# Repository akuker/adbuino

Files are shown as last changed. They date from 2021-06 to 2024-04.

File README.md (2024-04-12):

# Background

"Adbuino" has a long history of different people tinkering with it. Just to provide some clarity...

- ORIGINAL PS/2 version - In the beginning - bbraun created the adbuino project and generously open sourced it. The links aren't working anymore, but the original SVN repo was [bbraun's](http://synack.net/svn/adbduino/)
- Difegue PS/2 version - 2020 - Difegue's version of the [adbuino](https://github.com/Difegue/Chaotic-Realm), modified [bbraun's](http://synack.net/svn/adbduino/) version, with some extra code added to alleviate issues with his own PS/2 keyboard.
- akuker USB version - 2022 - akuker converted Difegue's version to use a USB controller and created a PCB design using KiCad.
- [QuokkADB](QuokkADB.md) - 2023 - [Rabbit Hole computing](https://github.com/rabbitholecomputing) created a new PCB based on the RP2040 (instead of Atmel chip). [Morio](https://github.com/morio), ported the code to the dual core RP2040, removed the dependency on the expensive MAX3421E USB controller and updated it to a PlatformIO project. Morio graciously merged their code changes back into [akuker/adbuino](http://github.com/akuker/adbuino)
- [HIDHopper_ADB](https://github.com/TechByAndroda/HIDHopper_ADB) - 2023 - [TechByAndroda](https://github.com/TechByAndroda) forked the repo and made a new PCB that uses a Raspberry Pi Pico (instead of a chip-down RP2040)

Its GPL code. It belongs to the community. Do fun GPL stuff with it. 

# akuker USB Adbuino
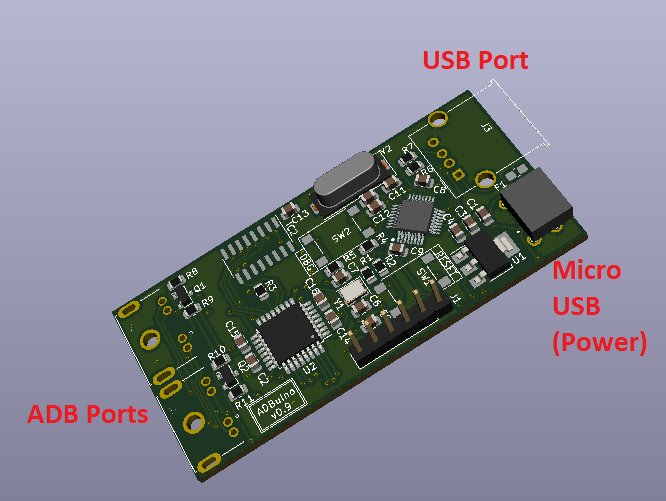
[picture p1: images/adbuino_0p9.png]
ADBuino picture

This is a fork of Difegue's version of the [adbuino](https://github.com/Difegue/Chaotic-Realm), which was a modified version of [bbraun's](http://synack.net/svn/adbduino/) PS/2 to ADB arduino sketch, with some extra code added to alleviate issues with his own PS/2 keyboard.  For Difegue's original write-up, please read more info [here.](https://tvc-16.science/adbuino-ps2.html).

# QuokkADB
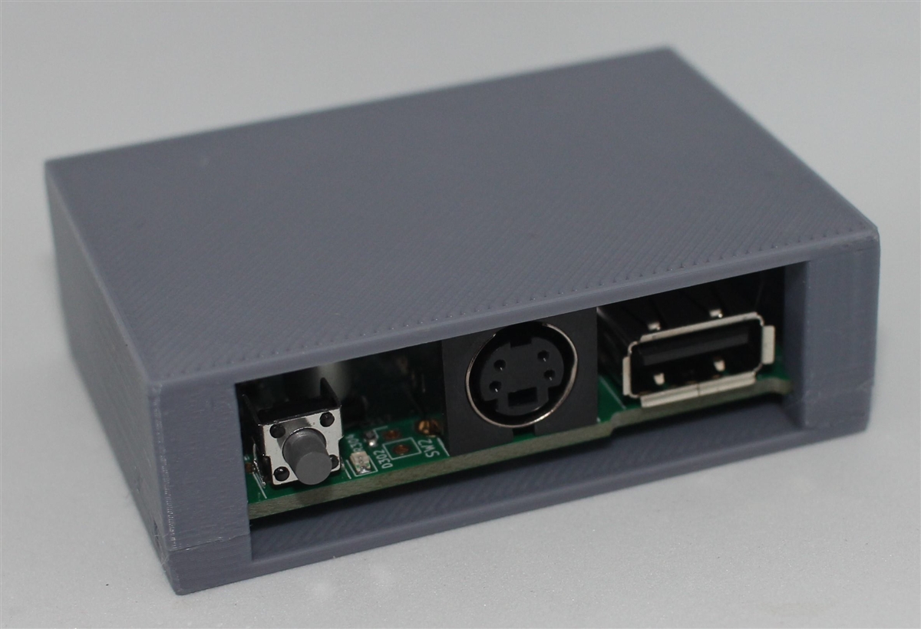
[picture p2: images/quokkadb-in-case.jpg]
QuokkADB picture

QuokkADB is a modified version of [adbuino](https://github.com/akuker/adbuino). It is targeted to the Rabbit Hole Computing's QuokkADB device. QuokkADB is a Raspberry Pi RP2040 based device that takes in USB inputs from a keyboard and/or mouse and outputs Apple's ADB (Apple Desktop Bus).  Further information can be found in the [QuokkADB.md](QuokkADB.md) file. 

# HIDHopper_ADB
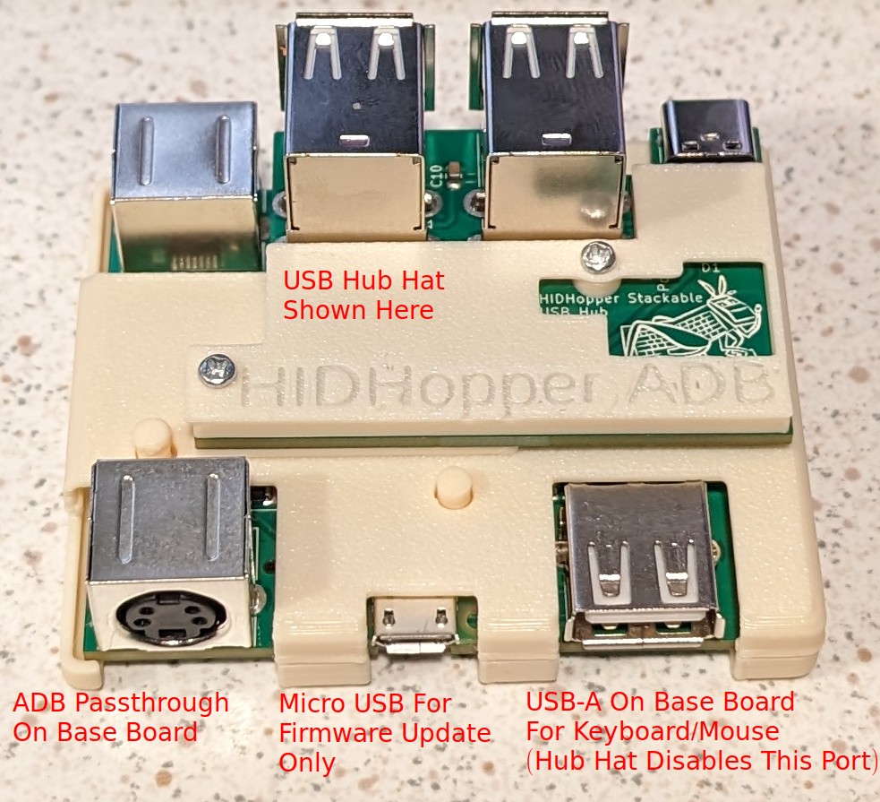
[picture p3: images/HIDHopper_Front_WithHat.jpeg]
HIDHopper picture

HIDHopper_ADB is a modified (forked) version of adbuino and QuokkADB. It is a Raspberry Pi Pico based hardware device which converts USB keyboard and mouse inputs to the Apple Desktop Bus (ADB) standard.

# Hack-y Alternative
The USB ADBuino is essentially a "value-engineered" version of a bunch of off-the-shelf components. 

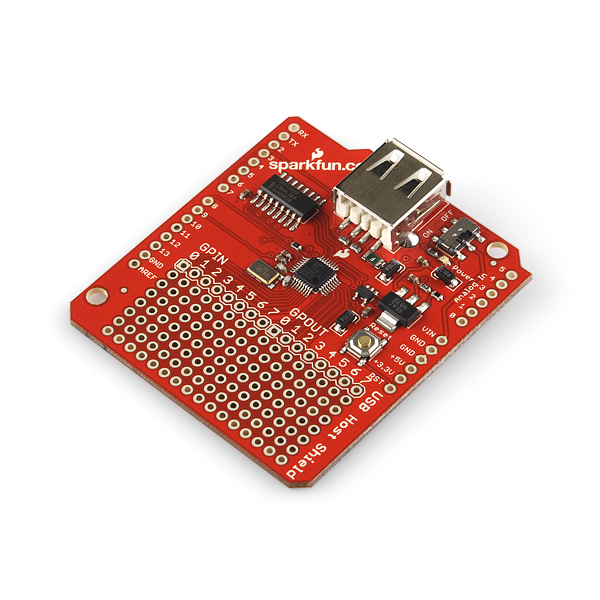
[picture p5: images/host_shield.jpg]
  
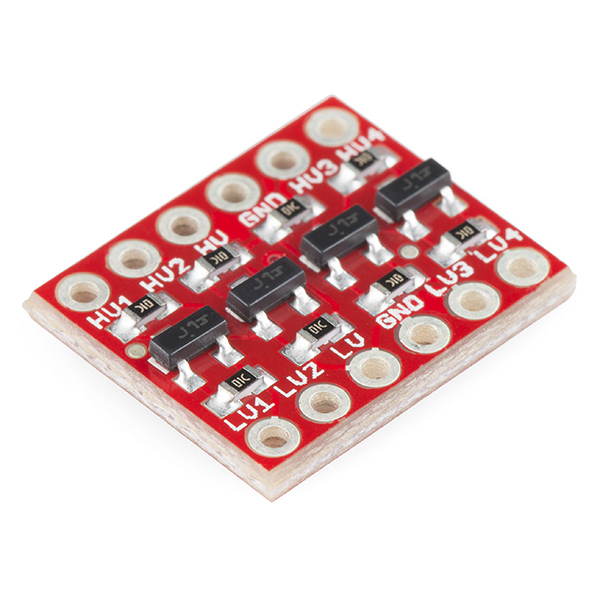
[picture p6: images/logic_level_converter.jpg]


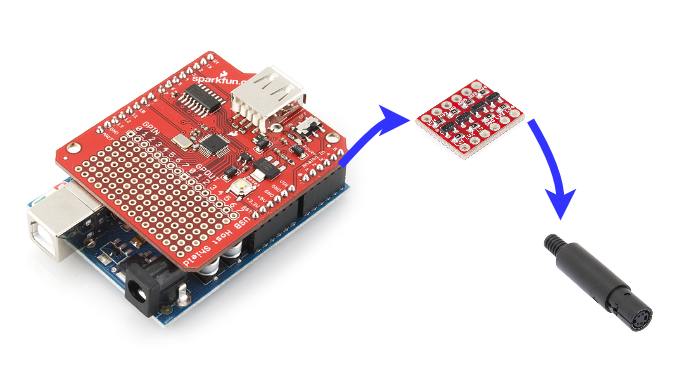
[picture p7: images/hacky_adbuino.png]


# How to build and flash an adbuino

Note: This software is intended to be compiled in an Ubuntu Linux environment.

Any dependencies that are configured in the PlatformIO project (such as TinyUSB) will automatically be downloaded. Make sure you are connected to the Internet the first time you build this software.

- Install [Visual Studio Code](https://code.visualstudio.com/)
- Install [Platform IO](https://platformio.org/install)
- Open Visual studio Code and open the directory ./src/adbuino
- Select the PlatformIO icon on the left
- Execute the `Build` project task
- Execute the `Upload` project task to flash your device

# What's this repo for?

The intent of this repository is to add "USB Host" support to the original ADB design. This will allow a USB keyboard and/or mouse to be used to drive an ADB host, as well as PS/2. 

The [BMOW "Wombat"](https://www.bigmessowires.com/usb-wombat/) is a closed-source alternative to adbuino. The [BMOW "Wombat"](https://www.bigmessowires.com/usb-wombat/) is an AWESOME project, but doesn't allow external contributors. 

# References
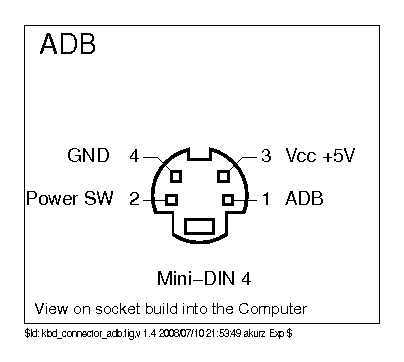
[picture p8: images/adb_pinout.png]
ADB Pinout


## Protocol/Software Documentation
- [Apple ADB Manager Documenation](https://developer.apple.com/library/archive/documentation/mac/pdf/Devices/ADB_Manager.pdf)
- [ADB Overview](https://www.lopaciuk.eu/2021/03/26/apple-adb-protocol.html)
- [Microchip Application Note AN591](http://www.t-es-t.hu/download/microchip/an591b.pdf)
- [TMK Documentation](https://github.com/tmk/tmk_keyboard/wiki/Apple-Desktop-Bus)

## Other libraries
- [TinyUSB Library](https://github.com/raspberrypi/tinyusb)
- [MiSTER adb hardware emulation](https://github.com/mist-devel/plus_too/blob/master/adb.v)

## Development resources
- [Running OpenOCD without root](https://forgge.github.io/theCore/guides/running-openocd-without-sudo.html)

## Hardware Links
- [ADB Connector - mouser](https://www.mouser.com/ProductDetail/TE-Connectivity/5749181-1?qs=XlZqES4cpWbRcAMR%2FcJqkQ%3D%3D)

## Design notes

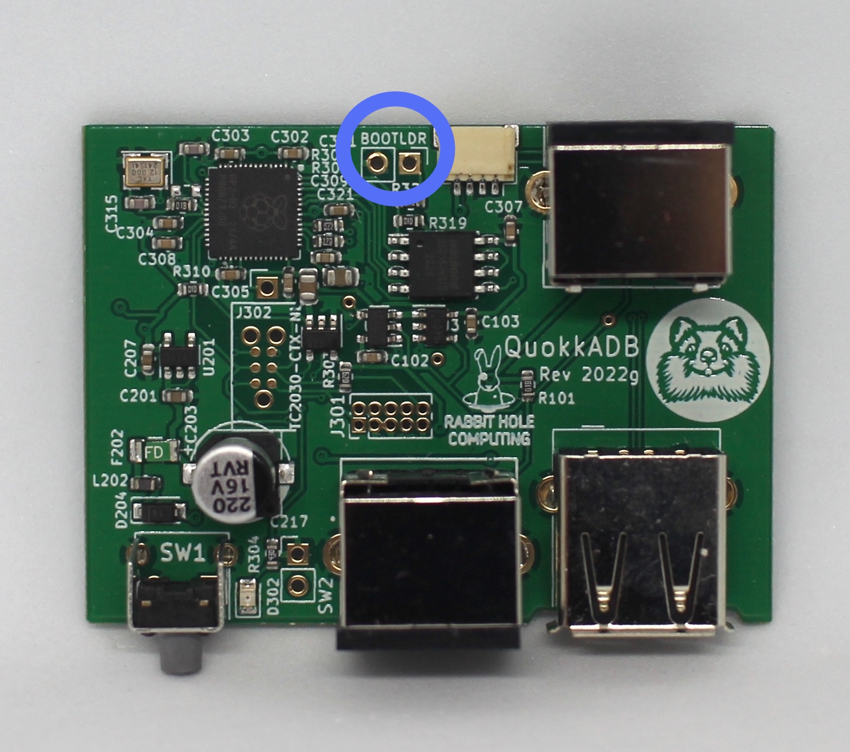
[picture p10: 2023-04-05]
images/quokkadb-bootloader.jpg

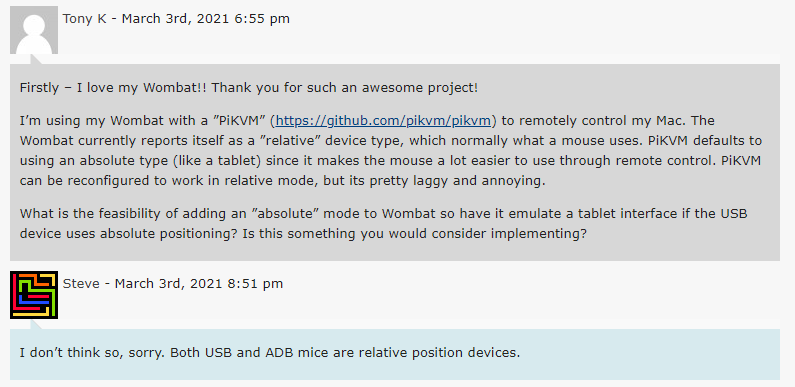
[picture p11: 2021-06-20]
images/wombat_discussion.png

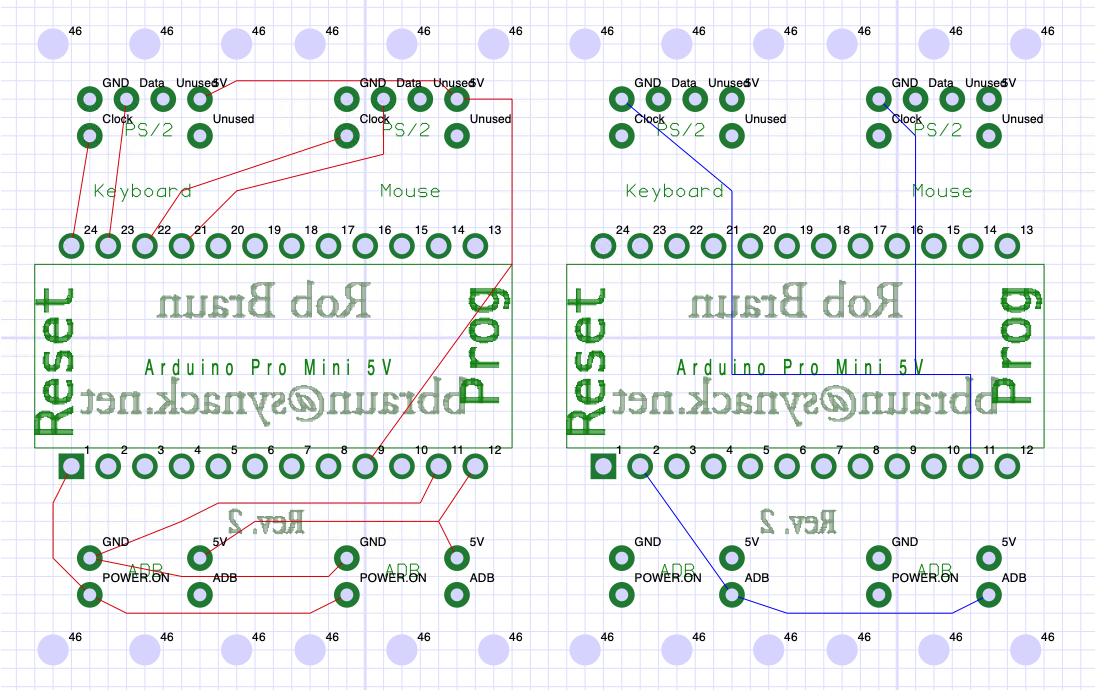
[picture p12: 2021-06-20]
hw/osmond.png

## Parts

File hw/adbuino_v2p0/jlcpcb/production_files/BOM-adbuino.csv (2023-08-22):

Comment | Designator | Footprint | LCSC
LED_Small | D1,D2,D3 | LED_0805_2012Metric | C2297
10k | R1,R12,R2,R3,R4,R5,R6 | R_0402_1005Metric | C25744
U254-051N-4BH806 | J2 | U254051N4BH806 | C319170
Polyfuse | F1,F2 | Fuse_0805_2012Metric | C66452
BSS138 | Q1,Q2 | SOT-23 | C78284
D_Schottky | D4,D5 | D_SOD-123 | C8598
Mini-DIN-4 | J5 | CUI_MD2-40ST-SMT
Pico | U2 | Customized_RPi_Pico_SMD_TH
TestPoint_Small | TP3 | TestPoint_Pad_D1.0mm
TestPoint_Small | TP2 | TestPoint_Pad_D1.0mm
TestPoint_Small | TP1 | TestPoint_Pad_D1.0mm
Mini-DIN-4 | J4 | CUI_MD2-40ST-SMT
SolderJumper_2_Open | JP5 | SolderJumper-2_P1.3mm_Open_RoundedPad1.0x1.5mm

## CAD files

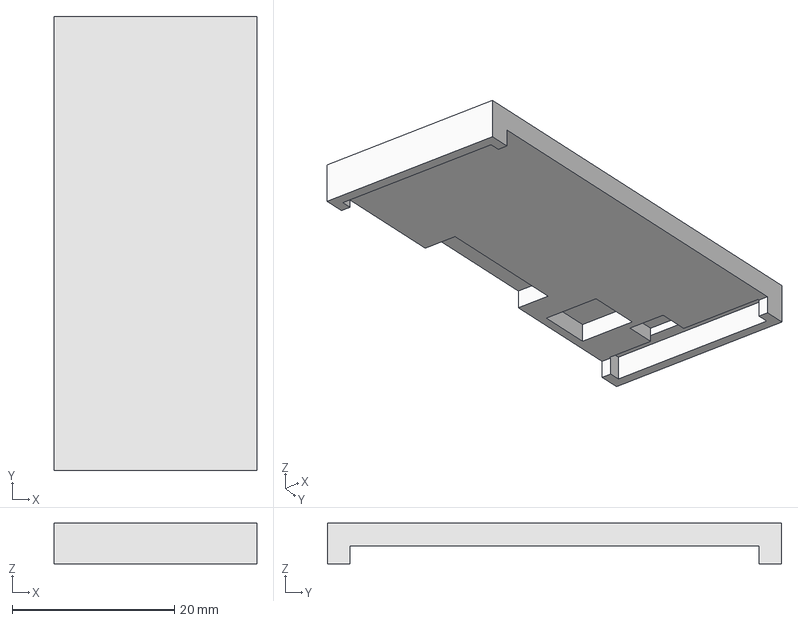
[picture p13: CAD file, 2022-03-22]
case/adbuino_case2.FCStd
25.0 x 56.0 x 5.00 mm

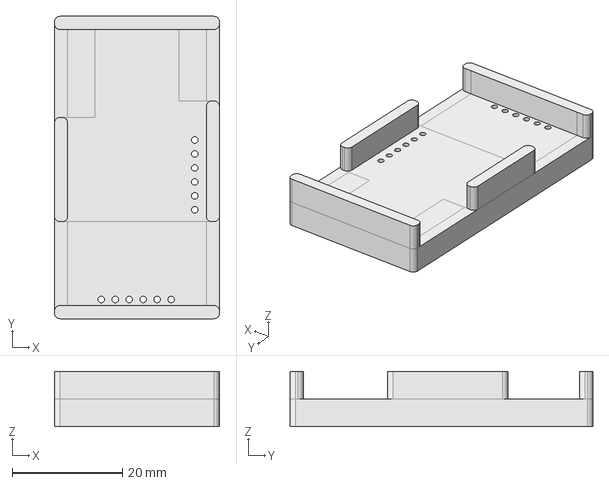
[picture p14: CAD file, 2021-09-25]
hw/adbuino_pogo_holder/adbuino_pogo_holder.FCStd
30.0 x 55.0 x 10.0 mm

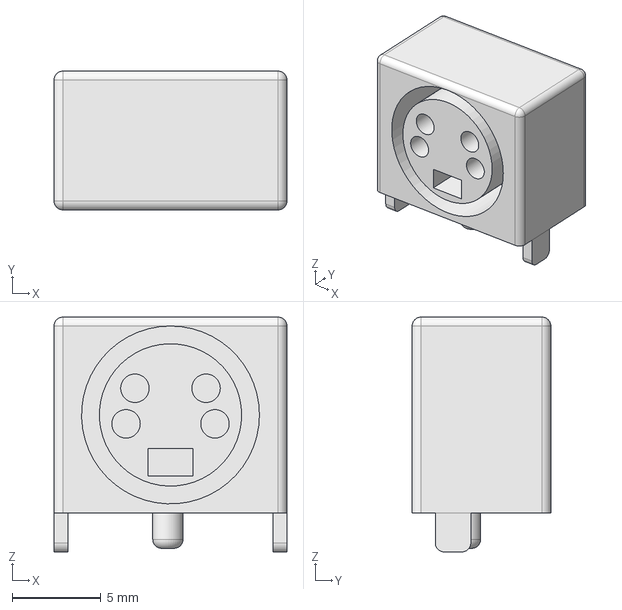
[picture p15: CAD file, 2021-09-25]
hw/adbuino_v2p0/MD2-40ST-SMT.FCStd
13.1 x 7.80 x 13.2 mm

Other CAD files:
hw/adbuino_pogo_holder/adbuino_pogo_holder.stl

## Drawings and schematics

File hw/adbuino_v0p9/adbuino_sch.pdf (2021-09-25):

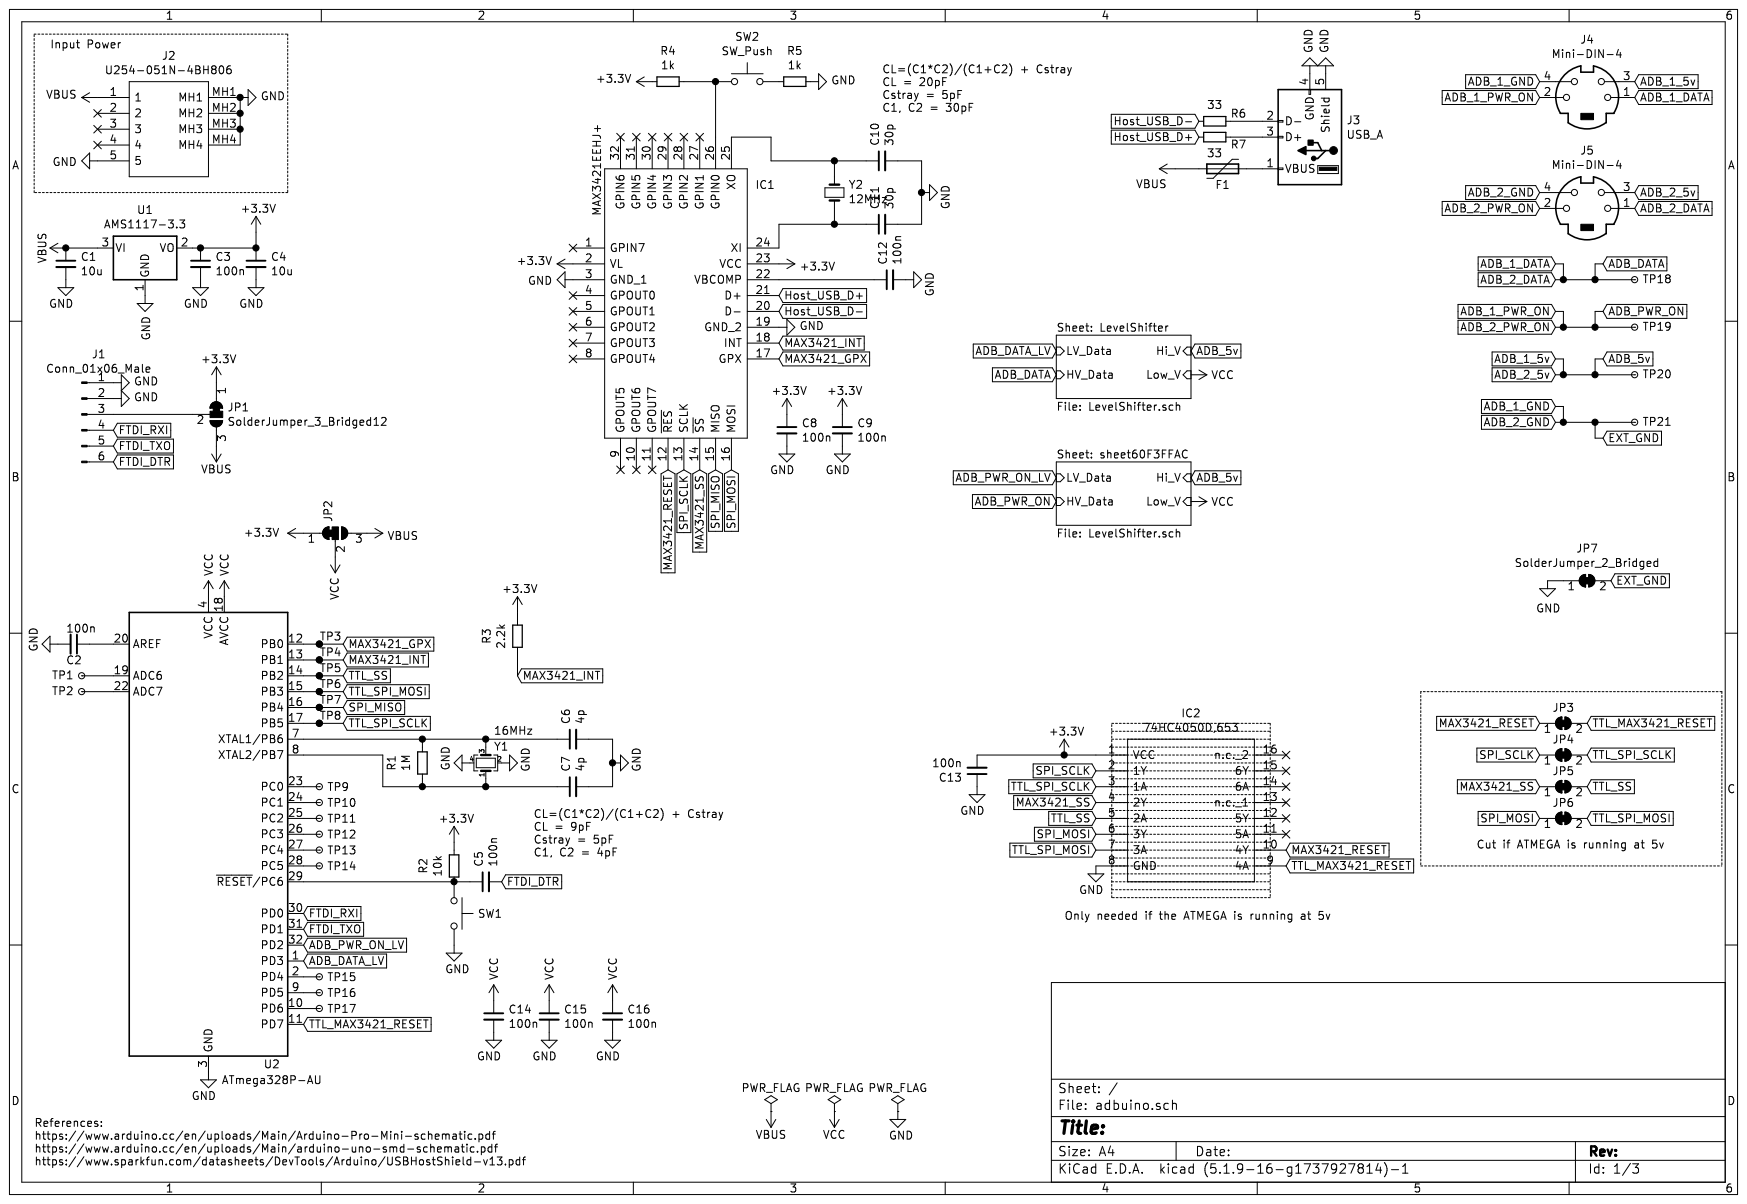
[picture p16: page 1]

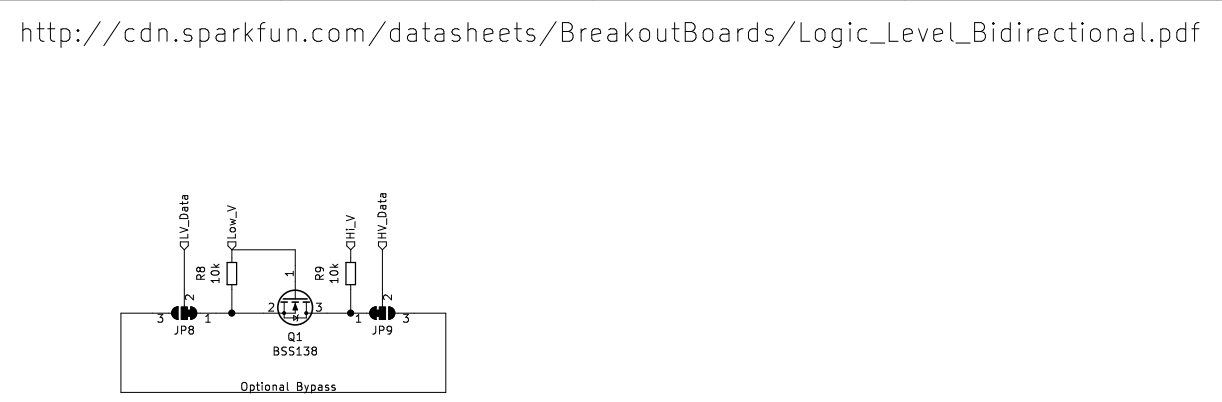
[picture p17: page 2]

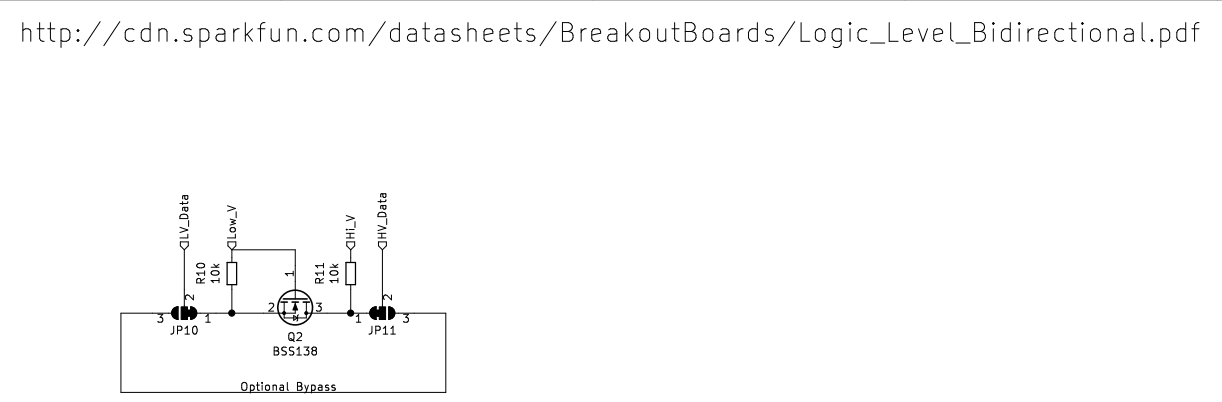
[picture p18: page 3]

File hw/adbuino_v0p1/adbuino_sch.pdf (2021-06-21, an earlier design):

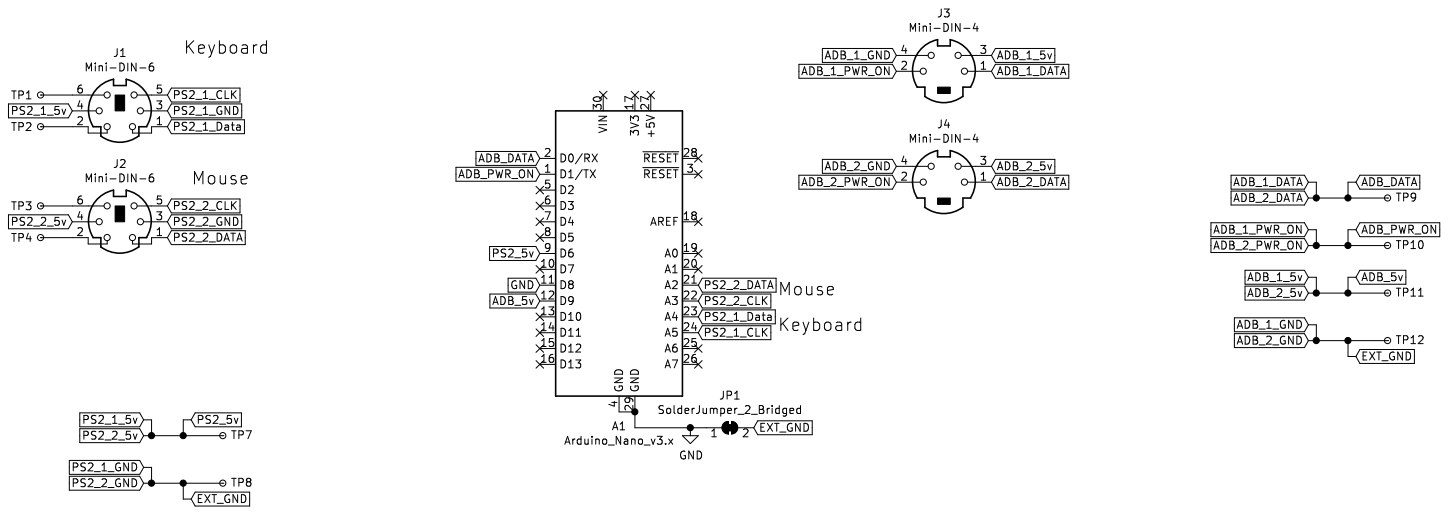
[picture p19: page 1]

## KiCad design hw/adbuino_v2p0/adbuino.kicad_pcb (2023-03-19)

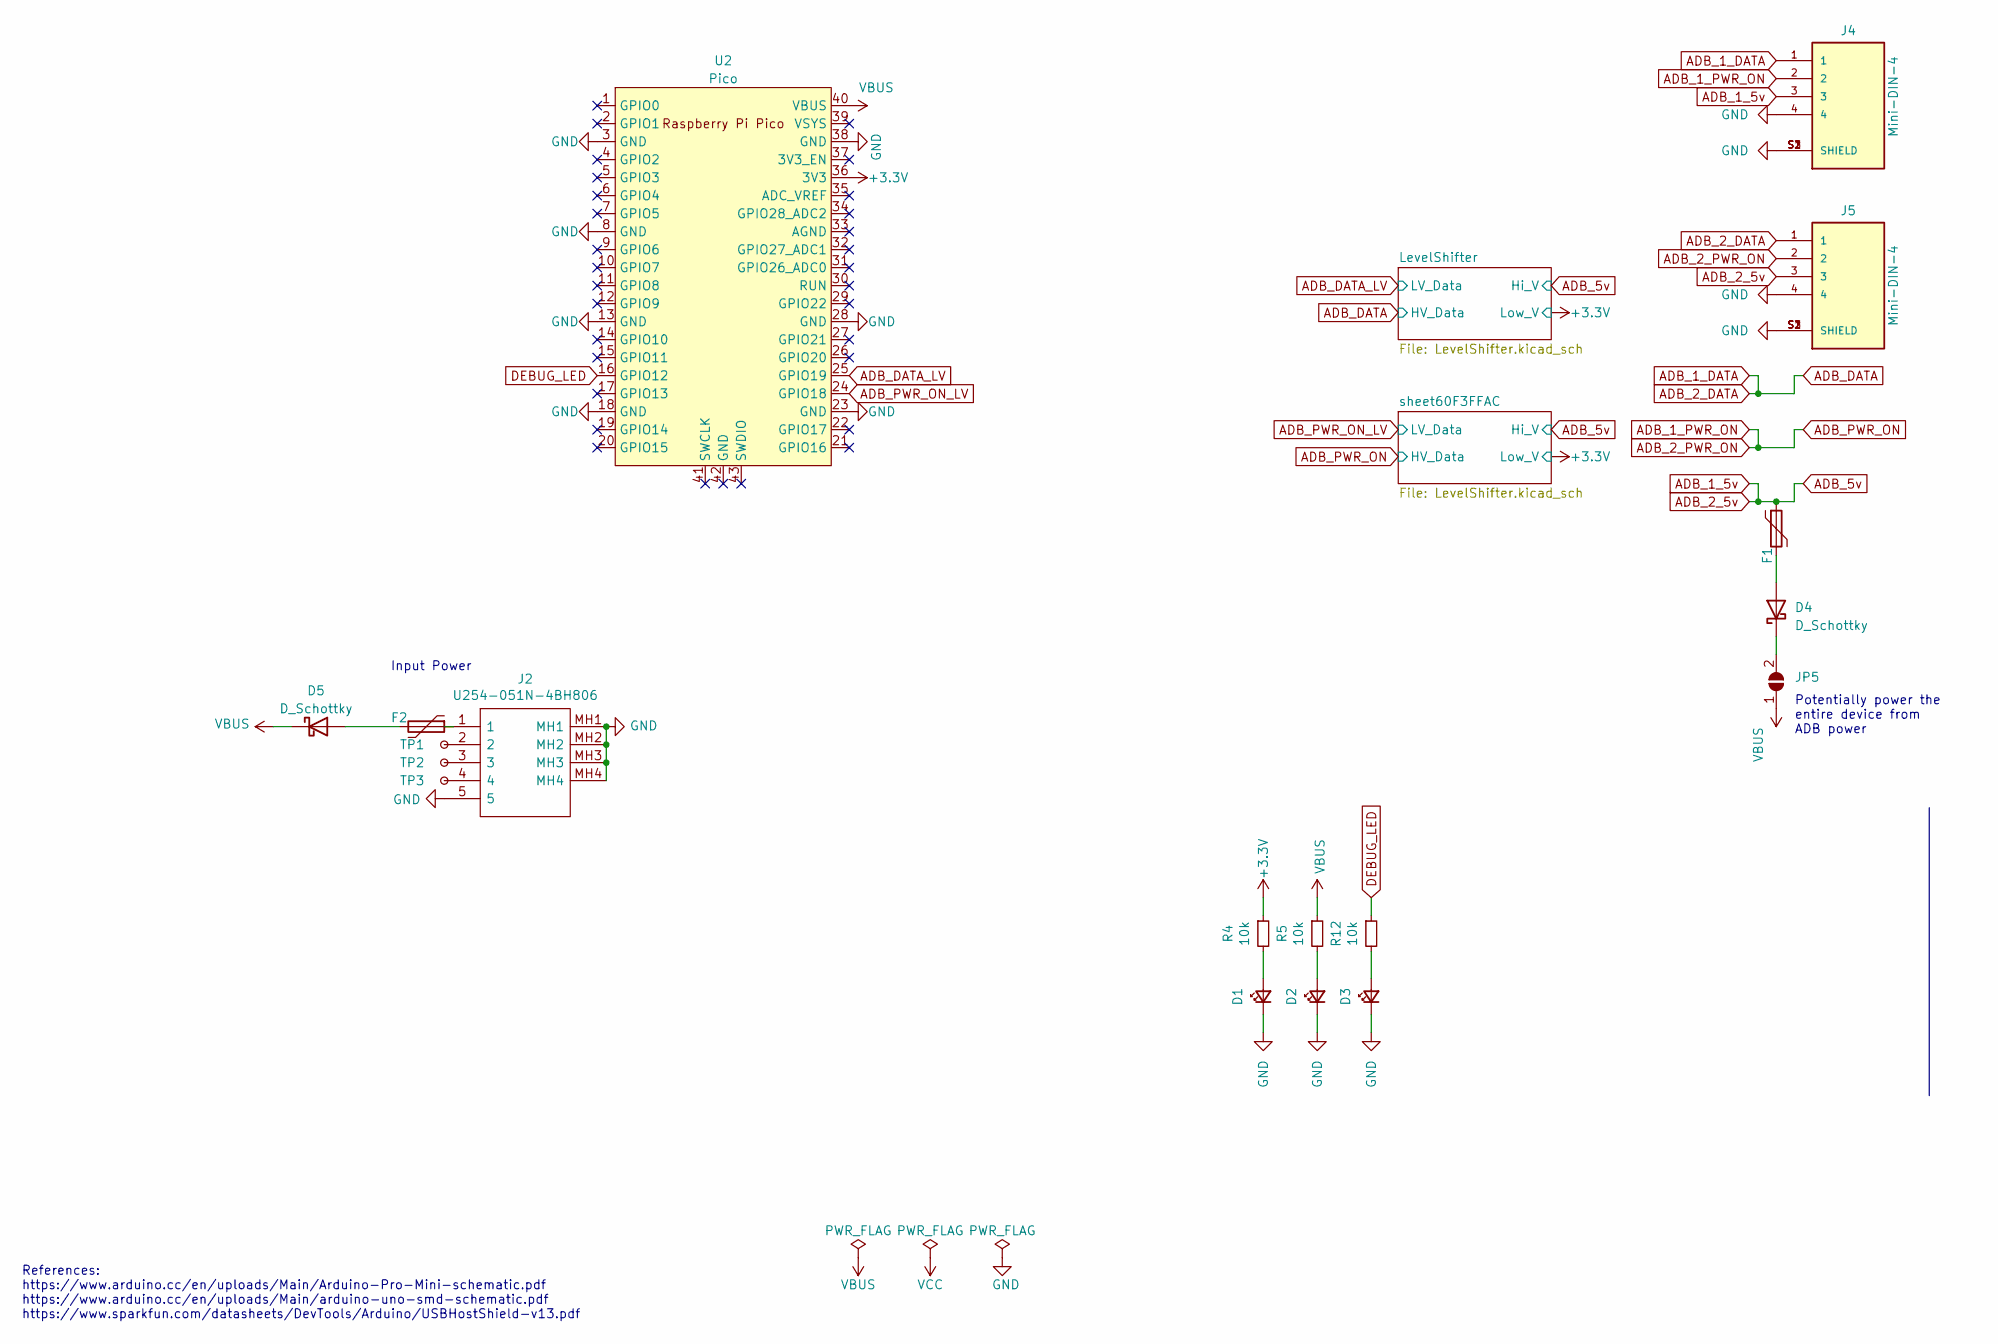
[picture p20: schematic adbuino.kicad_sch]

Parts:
D1, D2, D3: LED_Small; LED_0805_2012Metric; LCSC C2297
D4, D5: D_Schottky; D_SOD-123; LCSC C8598
F1, F2: Polyfuse; Fuse_0805_2012Metric; LCSC C66452
J2: U254-051N-4BH806; U254051N4BH806; Manufacturer_Part_Number U254-051N-4BH806; LCSC C319170
J4, J5: Mini-DIN-4; CUI_MD2-40ST-SMT
JP5: SolderJumper_2_Open; SolderJumper-2_P1.3mm_Open_RoundedPad1.0x1.5mm
R4, R5, R12: 10k; R_0402_1005Metric; LCSC C25744
TP1, TP2, TP3: TestPoint_Small; TestPoint_Pad_D1.0mm
U2: Pico; Customized_RPi_Pico_SMD_TH

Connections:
+3V3: R4.1, U2.36 (3V3); also elsewhere on the board
ADB_1_5v: F1.1, J4.3, J5.3; also elsewhere on the board
ADB_1_DATA: J4.1, J5.1; also elsewhere on the board
ADB_1_PWR_ON: J4.2, J5.2; also elsewhere on the board
ADB_DATA_LV: U2.25 (GPIO19); also elsewhere on the board
ADB_PWR_ON_LV: U2.24 (GPIO18); also elsewhere on the board
DEBUG_LED: R12.1, U2.16 (GPIO12)
GND: D1.1 (K), D2.1 (K), D3.1 (K), J2.5, J2.MH1, J2.MH2, J2.MH3, J2.MH4, J4.4, J4.S1 (SHIELD), J4.S2 (SHIELD), J4.S3 (SHIELD), J5.4, J5.S1 (SHIELD), J5.S2 (SHIELD), J5.S3 (SHIELD), U2.3 (GND), U2.8 (GND), U2.13 (GND), U2.18 (GND), U2.23 (GND), U2.28 (GND), U2.38 (GND)
unnamed: D1.2 (A), R4.2
unnamed: D2.2 (A), R5.2
unnamed: D3.2 (A), R12.2
unnamed: D4.2 (A), F1.2
unnamed: D4.1 (K), JP5.2 (B)
unnamed: D5.2 (A), F2.2
unnamed: F2.1, J2.1
unnamed: J2.2, TP1.1
unnamed: J2.3, TP2.1
unnamed: J2.4, TP3.1
VBUS: D5.1 (K), JP5.1 (A), R5.1, U2.40 (VBUS)

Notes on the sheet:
Input Power
References: https://www.arduino.cc/en/uploads/Main/Arduino-Pro-Mini-schematic.pdf https://www.arduino.cc/en/uploads/Main/arduino-uno-smd-schematic.pdf https://www.sparkfun.com/datasheets/DevTools/Arduino/USBHostShield-v13.pdf
Potentially power the entire device from ADB power

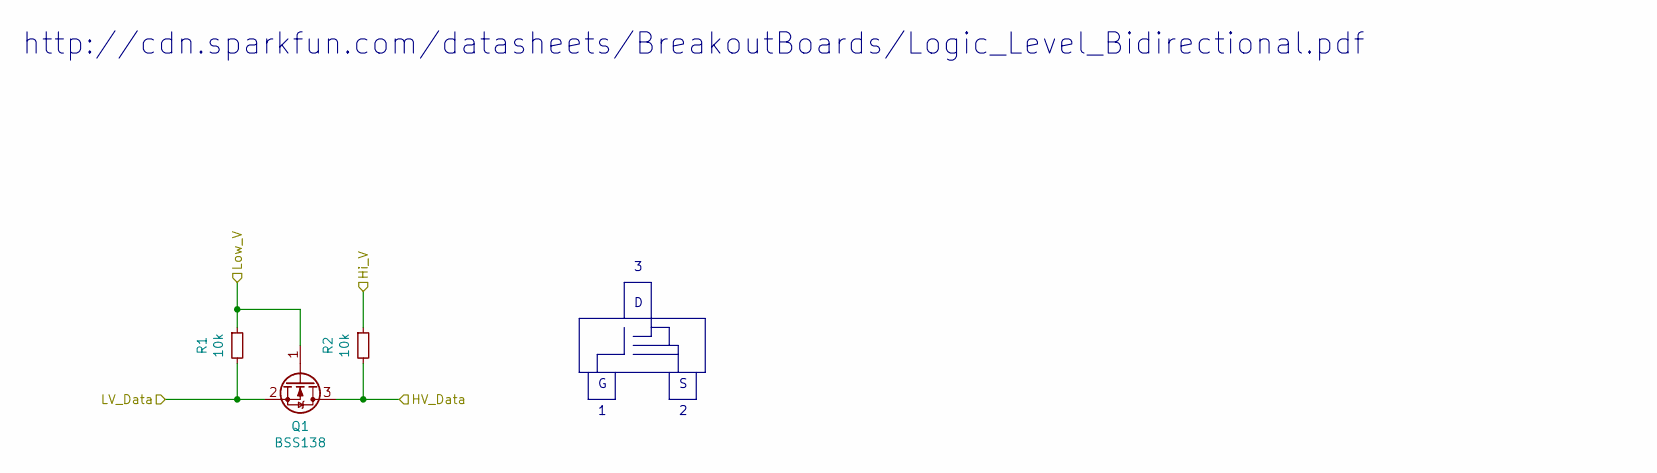
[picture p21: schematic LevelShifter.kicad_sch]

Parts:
Q1: BSS138; SOT-23; LCSC C78284
R1, R2: 10k; R_0402_1005Metric; LCSC C25744

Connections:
+3V3: Q1.1 (G), R1.1; also elsewhere on the board
ADB_1_5v: R2.1; also elsewhere on the board
ADB_1_PWR_ON: Q1.3 (D), R2.2; also elsewhere on the board
ADB_PWR_ON_LV: Q1.2 (S), R1.2; also elsewhere on the board

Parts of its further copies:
Q2: BSS138; SOT-23; LCSC C78284
R3, R6: 10k; R_0402_1005Metric; LCSC C25744

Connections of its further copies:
+3V3: Q2.1 (G), R3.1; also elsewhere on the board
ADB_1_5v: R6.1; also elsewhere on the board
ADB_1_DATA: Q2.3 (D), R6.2; also elsewhere on the board
ADB_DATA_LV: Q2.2 (S), R3.2; also elsewhere on the board

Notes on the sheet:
http://cdn.sparkfun.com/datasheets/BreakoutBoards/Logic_Level_Bidirectional.pdf

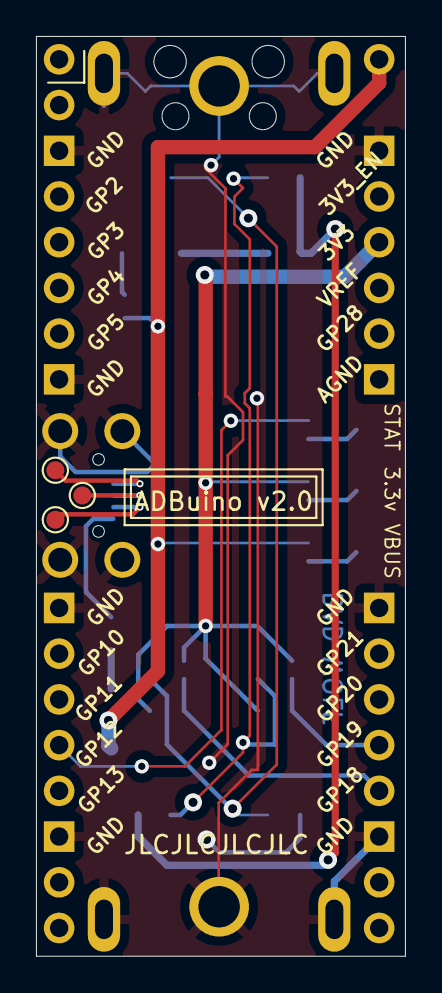
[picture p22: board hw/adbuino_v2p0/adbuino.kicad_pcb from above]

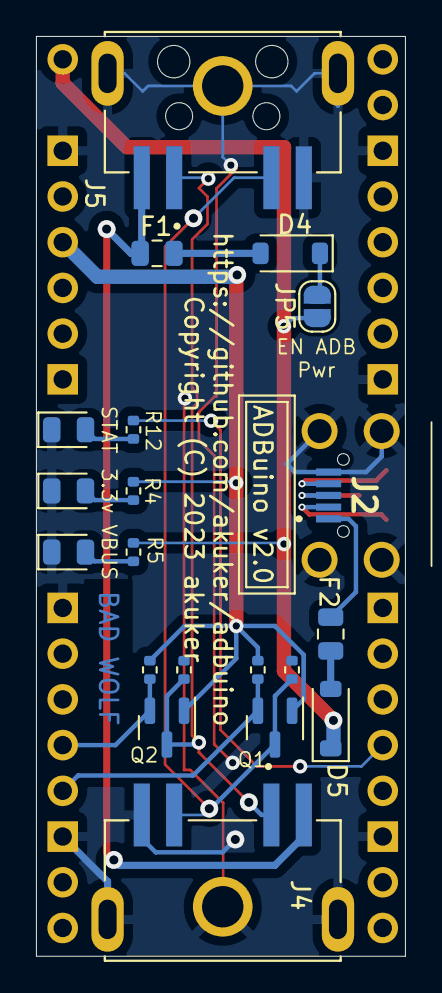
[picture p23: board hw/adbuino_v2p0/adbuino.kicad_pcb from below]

Board: 2 copper layers, 20.5 x 51.1 mm, 24 parts (20 on the bottom side), 19 nets.

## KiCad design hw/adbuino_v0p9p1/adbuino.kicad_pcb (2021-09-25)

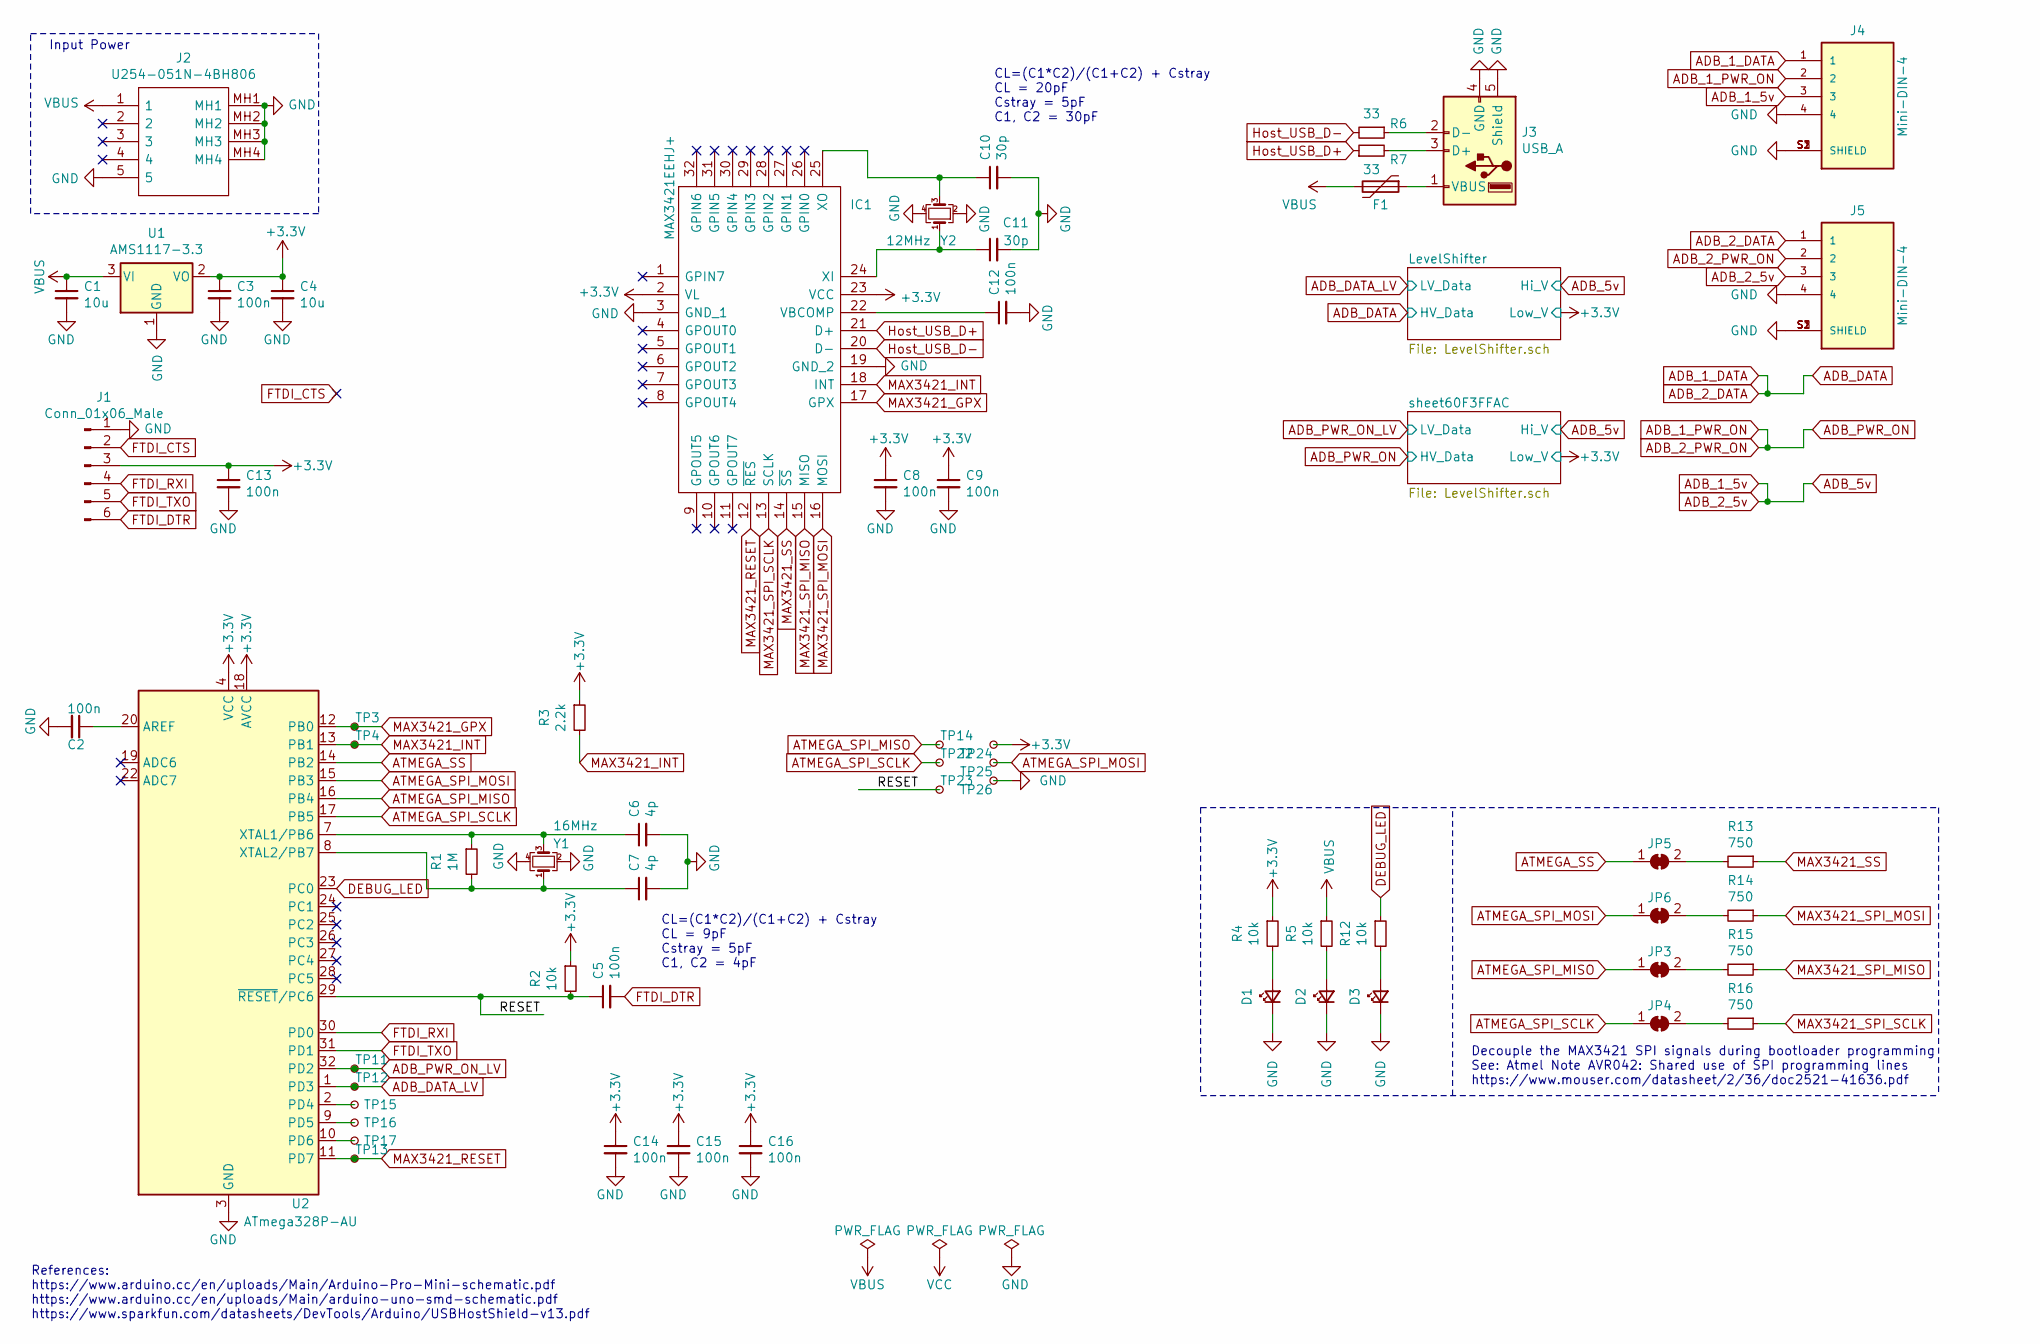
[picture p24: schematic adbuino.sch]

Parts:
C1, C4: 10u; C_0402_1005Metric; LCSC C15525
C2, C3, C5, C8, C9, C12, C13, C14, C15, C16: 100n; C_0402_1005Metric; LCSC C1525
C6, C7: 4p; C_0402_1005Metric; LCSC C318615
C10, C11: 30p; C_0402_1005Metric; LCSC C1570
D1, D2, D3: LED_Small; LED_0805_2012Metric; LCSC C2297
F1: Polyfuse; Fuse_0805_2012Metric_Castellated; LCSC C66452
IC1: MAX3421EEHJ+; QFP50P700X700X120-32N; Mouser Part Number 700-MAX3421EEHJ
J1: Conn_01x06_Male; PinHeader_1x06_P2.54mm_Vertical
J2: U254-051N-4BH806; U254051N4BH806; Manufacturer_Part_Number U254-051N-4BH806; LCSC C319170
J3: USB_A; USB_A_Molex_67643_Horizontal; LCSC C2346
J4, J5: Mini-DIN-4; CUI_MD2-40ST-SMT
JP3, JP4, JP5, JP6: SolderJumper_2_Bridged; SolderJumper-2_P1.3mm_Bridged_RoundedPad1.0x1.5mm
R1: 1M; R_0402_1005Metric; LCSC C26083
R2, R4, R5, R12: 10k; R_0402_1005Metric; LCSC C25744
R3: 2.2k; R_0402_1005Metric; LCSC C25879
R6, R7: 33; R_0402_1005Metric; LCSC C25105
R13, R14, R15, R16: 750; R_0402_1005Metric; LCSC C445595
TP3, TP4, TP11, TP12, TP13, TP14, TP15, TP16, TP17, TP22, TP23, TP24, TP25, TP26: TestPoint_Small; TestPoint_Pad_D1.0mm
U1: AMS1117-3.3; SOT-223-3_TabPin2; LCSC C6186
U2: ATmega328P-AU; TQFP-32_7x7mm_P0.8mm; LCSC C14877
Y1: 16MHz; Crystal_SMD_3225-4Pin_3.2x2.5mm; LCSC C13738
Y2: 12MHz; Crystal_SMD_3225-4Pin_3.2x2.5mm; LCSC C9002

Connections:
+3V3: C3.1, C4.1, C8.1, C9.1, C13.1, C14.1, C15.1, C16.1, IC1.2 (VL), IC1.23 (VCC), J1.3, R2.1, R3.1, R4.1, TP24.1, U1.2 (VO), U2.4 (VCC), U2.6 (VCC), U2.18 (AVCC); also elsewhere on the board
/RESET: C5.1, R2.2, TP23.1, U2.29 (~RESET~/PC6)
ADB_1_5v: J4.3, J5.3; also elsewhere on the board
ADB_1_DATA: J4.1, J5.1; also elsewhere on the board
ADB_1_PWR_ON: J4.2, J5.2; also elsewhere on the board
ADB_DATA_LV: TP12.1, U2.1 (PD3); also elsewhere on the board
ADB_PWR_ON_LV: TP11.1, U2.32 (PD2); also elsewhere on the board
ATMEGA_SPI_MISO: JP3.1 (A), TP14.1, U2.16 (PB4)
ATMEGA_SPI_MOSI: JP6.1 (A), TP25.1, U2.15 (PB3)
ATMEGA_SPI_SCLK: JP4.1 (A), TP22.1, U2.17 (PB5)
ATMEGA_SS: JP5.1 (A), U2.14 (PB2)
DEBUG_LED: R12.1, U2.23 (PC0)
FTDI_DTR: C5.2, J1.6
FTDI_RXI: J1.4, U2.30 (PD0)
FTDI_TXO: J1.5, U2.31 (PD1)
GND: C1.2, C2.2, C3.2, C4.2, C6.2, C7.2, C8.2, C9.2, C10.2, C11.2, C12.2, C13.2, C14.2, C15.2, C16.2, D1.1 (K), D2.1 (K), D3.1 (K), IC1.3 (GND_1), IC1.19 (GND_2), J1.1, J2.5, J2.MH1, J2.MH2, J2.MH3, J2.MH4, J3.4 (GND), J3.5 (Shield), J4.4, J4.S1 (SHIELD), J4.S2 (SHIELD), J4.S3 (SHIELD), J5.4, J5.S1 (SHIELD), J5.S2 (SHIELD), J5.S3 (SHIELD), TP26.1, U1.1 (GND), U2.3 (GND), U2.5 (GND), U2.21 (GND), Y1.2, Y1.4, Y2.2, Y2.4
Host_USB_D+: IC1.21 (D+), R7.1
Host_USB_D-: IC1.20 (D-), R6.2
MAX3421_GPX: IC1.17 (GPX), TP3.1, U2.12 (PB0)
MAX3421_INT: IC1.18 (INT), R3.2, TP4.1, U2.13 (PB1)
MAX3421_RESET: IC1.12 (~RES), TP13.1, U2.11 (PD7)
MAX3421_SPI_MISO: IC1.15 (MISO), R15.1
MAX3421_SPI_MOSI: IC1.16 (MOSI), R14.1
MAX3421_SPI_SCLK: IC1.13 (SCLK), R16.1
MAX3421_SS: IC1.14 (~SS), R13.1
unnamed: C2.1, U2.20 (AREF)
unnamed: C6.1, R1.1, U2.7 (XTAL1/PB6), Y1.3
unnamed: C7.1, R1.2, U2.8 (XTAL2/PB7), Y1.1
unnamed: C10.1, IC1.25 (XO), Y2.3
unnamed: C11.1, IC1.24 (XI), Y2.1
unnamed: C12.1, IC1.22 (VBCOMP)
unnamed: D1.2 (A), R4.2
unnamed: D2.2 (A), R5.2
unnamed: D3.2 (A), R12.2
unnamed: F1.1, J3.1 (VBUS)
unnamed: J3.2 (D-), R6.1
unnamed: J3.3 (D+), R7.2
unnamed: JP3.2 (B), R15.2
unnamed: JP4.2 (B), R16.2
unnamed: JP5.2 (B), R13.2
unnamed: JP6.2 (B), R14.2
unnamed: TP15.1, U2.2 (PD4)
unnamed: TP16.1, U2.9 (PD5)
unnamed: TP17.1, U2.10 (PD6)
VBUS: C1.1, F1.2, J2.1, R5.1, U1.3 (VI)

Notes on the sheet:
References: https://www.arduino.cc/en/uploads/Main/Arduino-Pro-Mini-schematic.pdf https://www.arduino.cc/en/uploads/Main/arduino-uno-smd-schematic.pdf https://www.sparkfun.com/datasheets/DevTools/Arduino/USBHostShield-v13.pdf
Input Power
CL=(C1*C2)/(C1+C2) + Cstray CL = 9pF Cstray = 5pF C1, C2 = 4pF
CL=(C1*C2)/(C1+C2) + Cstray CL = 20pF Cstray = 5pF C1, C2 = 30pF
Decouple the MAX3421 SPI signals during bootloader programming See: Atmel Note AVR042: Shared use of SPI programming lines https://www.mouser.com/datasheet/2/36/doc2521-41636.pdf

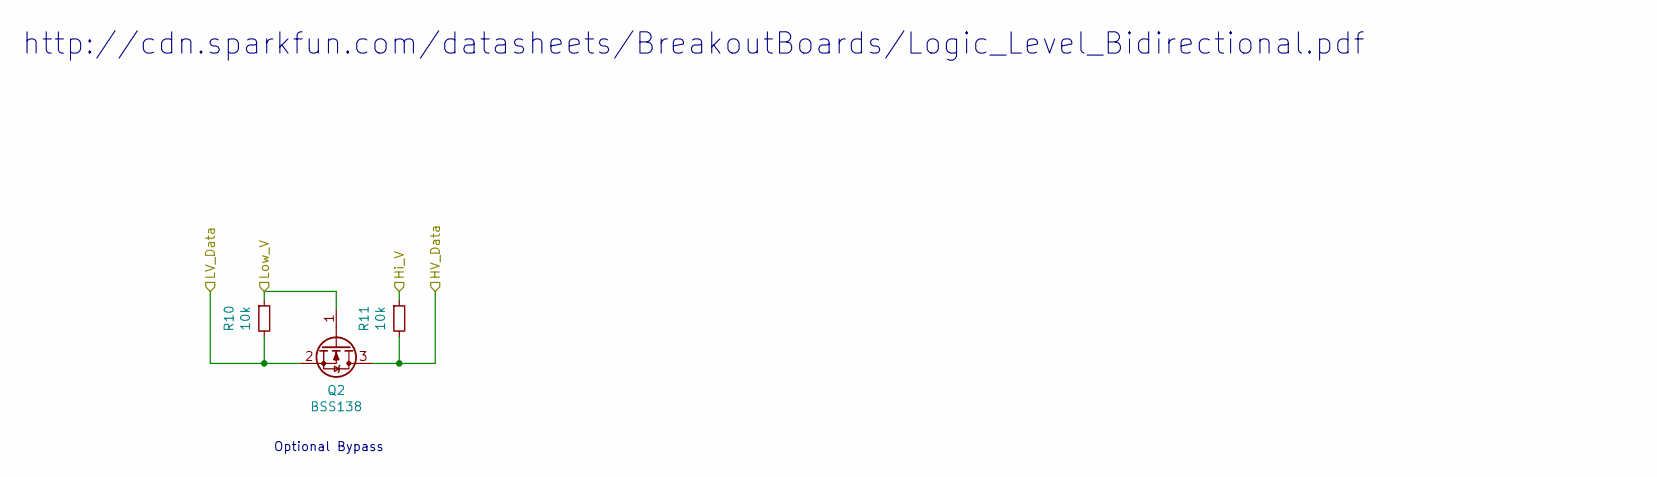
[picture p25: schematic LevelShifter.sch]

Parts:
Q1: BSS138; SOT-23; LCSC C52895
R8, R9: 10k; R_0402_1005Metric; LCSC C25744

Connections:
+3V3: Q1.1 (G), R8.1; also elsewhere on the board
ADB_1_5v: R9.1; also elsewhere on the board
ADB_1_DATA: Q1.3 (D), R9.2; also elsewhere on the board
ADB_DATA_LV: Q1.2 (S), R8.2; also elsewhere on the board

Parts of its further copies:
Q2: BSS138; SOT-23; LCSC C52895
R10, R11: 10k; R_0402_1005Metric; LCSC C25744

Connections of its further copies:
+3V3: Q2.1 (G), R10.1; also elsewhere on the board
ADB_1_5v: R11.1; also elsewhere on the board
ADB_1_PWR_ON: Q2.3 (D), R11.2; also elsewhere on the board
ADB_PWR_ON_LV: Q2.2 (S), R10.2; also elsewhere on the board

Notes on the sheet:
http://cdn.sparkfun.com/datasheets/BreakoutBoards/Logic_Level_Bidirectional.pdf
Optional Bypass

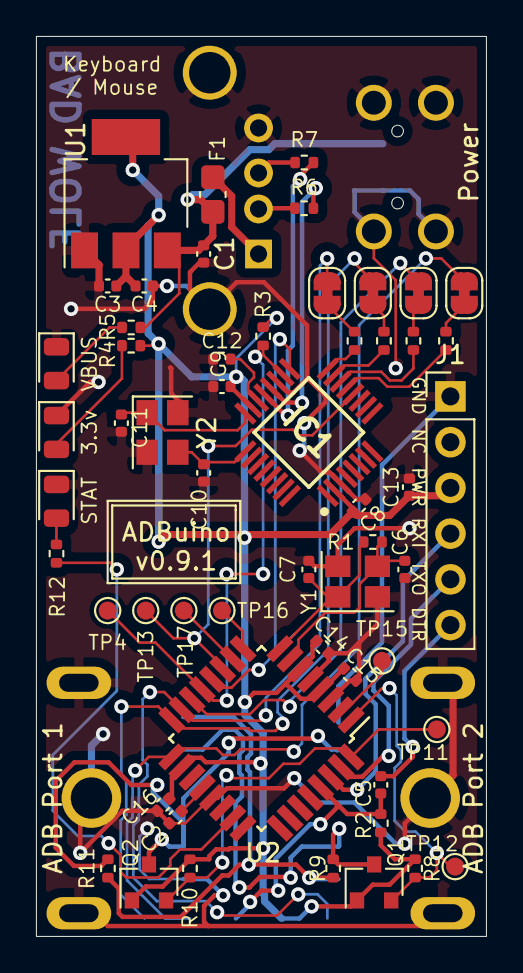
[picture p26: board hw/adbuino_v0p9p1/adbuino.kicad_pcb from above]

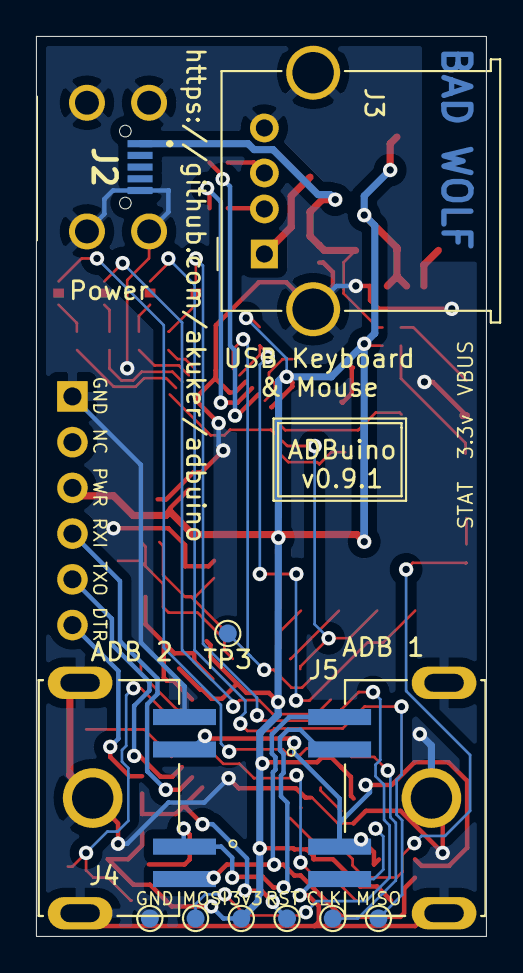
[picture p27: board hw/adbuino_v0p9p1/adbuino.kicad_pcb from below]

Board: 2 copper layers, 25.0 x 50.0 mm, 66 parts (11 on the bottom side), 45 nets.

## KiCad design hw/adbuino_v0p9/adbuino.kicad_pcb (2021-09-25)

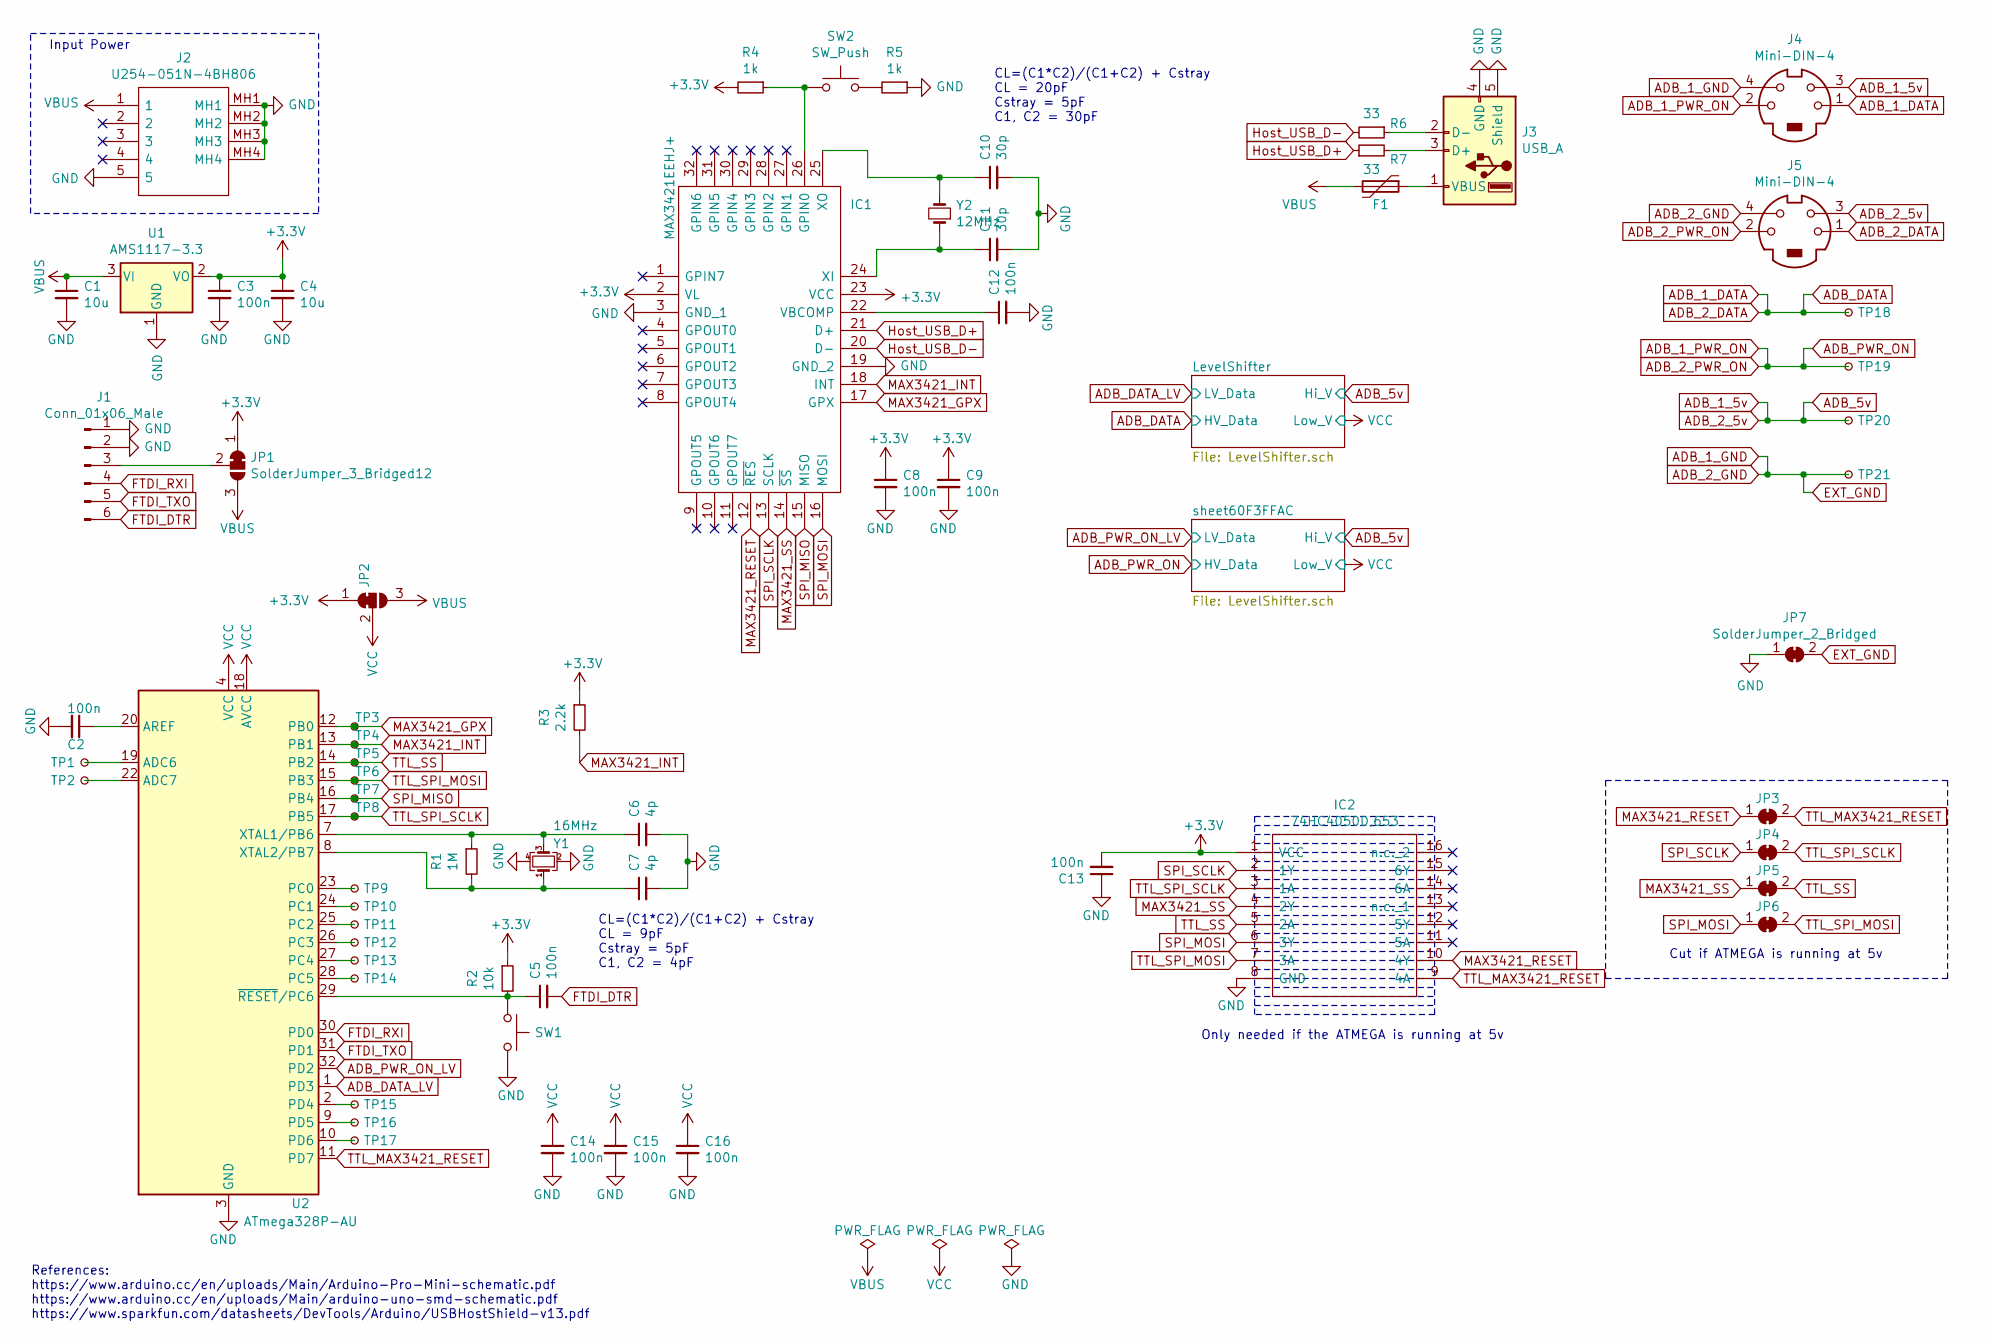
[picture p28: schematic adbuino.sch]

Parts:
C1, C4: 10u; C_0805_2012Metric; LCSC C15850
C2, C3, C5, C8, C9, C12, C13, C14, C15, C16: 100n; C_0805_2012Metric; LCSC C49678
C6, C7: 4p; C_0805_2012Metric; LCSC C170115
C10, C11: 30p; C_0805_2012Metric; LCSC C1809
F1: Polyfuse; Fuse_0805_2012Metric_Castellated; LCSC C66452
IC1: MAX3421EEHJ+; QFP50P700X700X120-32N; Mouser Part Number 700-MAX3421EEHJ
IC2: 74HC4050D,653; SOP-16_3.9x9.9mm_P1.27mm; Mouser Part Number 771-74HC4050D-T
J1: Conn_01x06_Male; PinHeader_1x06_P2.54mm_Vertical
J2: U254-051N-4BH806; U254051N4BH806; Manufacturer_Part_Number U254-051N-4BH806
J3: USB_A; USB_A_Molex_67643_Horizontal; LCSC C2346
J4, J5: Mini-DIN-4; CUI_MD2-40ST
JP1, JP2: SolderJumper_3_Bridged12; SolderJumper-3_P1.3mm_Bridged12_RoundedPad1.0x1.5mm_NumberL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
JP3, JP4, JP5, JP6, JP7: SolderJumper_2_Bridged; SolderJumper-2_P1.3mm_Bridged_RoundedPad1.0x1.5mm
R1: 1M; R_0805_2012Metric; LCSC C17514
R2: 10k; R_0805_2012Metric; LCSC C17414
R3: 2.2k; R_0805_2012Metric; LCSC C17520
R4, R5: 1k; R_0805_2012Metric; LCSC C17513
R6, R7: 33; R_0805_2012Metric; LCSC C17634
SW1, SW2: SW_Push; SW_Push_1P1T_NO_6x6mm_H9.5mm; LCSC C720316
TP1, TP2, TP3, TP4, TP5, TP6, TP7, TP8, TP9, TP10, TP11, TP12, TP13, TP14, TP15, TP16, TP17, TP18, TP19, TP20, TP21: TestPoint_Small; TestPoint_Pad_D1.0mm
U1: AMS1117-3.3; SOT-223-3_TabPin2; LCSC C6186
U2: ATmega328P-AU; TQFP-32_7x7mm_P0.8mm
Y1: 16MHz; Crystal_SMD_3225-4Pin_3.2x2.5mm; LCSC C13738
Y2: 12MHz; Crystal_SMD_HC49-SD; LCSC C108151

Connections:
+3V3: C3.1, C4.1, C8.1, C9.1, C13.2, IC1.2 (VL), IC1.23 (VCC), IC2.1 (VCC), JP1.1 (A), JP2.1 (A), R2.1, R3.1, R4.2, U1.2 (VO)
ADB_1_5v: J4.3, J5.3, TP20.1; also elsewhere on the board
ADB_1_DATA: J4.1, J5.1, TP18.1; also elsewhere on the board
ADB_1_GND: J4.4, J5.4, JP7.2 (B), TP21.1
ADB_1_PWR_ON: J4.2, J5.2, TP19.1; also elsewhere on the board
ADB_DATA_LV: U2.1 (PD3); also elsewhere on the board
ADB_PWR_ON_LV: U2.32 (PD2); also elsewhere on the board
FTDI_DTR: C5.2, J1.6
FTDI_RXI: J1.4, U2.30 (PD0)
FTDI_TXO: J1.5, U2.31 (PD1)
GND: C1.2, C2.2, C3.2, C4.2, C6.2, C7.2, C8.2, C9.2, C10.2, C11.2, C12.2, C13.1, C14.2, C15.2, C16.2, IC1.3 (GND_1), IC1.19 (GND_2), IC2.8 (GND), J1.1, J1.2, J2.5, J2.MH1, J2.MH2, J2.MH3, J2.MH4, J3.4 (GND), J3.5 (Shield), JP7.1 (A), R5.1, SW1.2, U1.1 (GND), U2.3 (GND), U2.5 (GND), U2.21 (GND), Y1.2, Y1.4
Host_USB_D+: IC1.21 (D+), R7.1
Host_USB_D-: IC1.20 (D-), R6.2
MAX3421_GPX: IC1.17 (GPX), TP3.1, U2.12 (PB0)
MAX3421_INT: IC1.18 (INT), R3.2, TP4.1, U2.13 (PB1)
MAX3421_RESET: IC1.12 (~RES), IC2.10 (4Y), JP3.1 (A)
MAX3421_SS: IC1.14 (~SS), IC2.4 (2Y), JP5.1 (A)
unnamed: C2.1, U2.20 (AREF)
unnamed: C5.1, R2.2, SW1.1, U2.29 (~RESET~/PC6)
unnamed: C6.1, R1.1, U2.7 (XTAL1/PB6), Y1.3
unnamed: C7.1, R1.2, U2.8 (XTAL2/PB7), Y1.1
unnamed: C10.1, IC1.25 (XO), Y2.2
unnamed: C11.1, IC1.24 (XI), Y2.1
unnamed: C12.1, IC1.22 (VBCOMP)
unnamed: F1.1, J3.1 (VBUS)
unnamed: IC1.26 (GPIN0), R4.1, SW2.1
unnamed: J1.3, JP1.2 (C)
unnamed: J3.2 (D-), R6.1
unnamed: J3.3 (D+), R7.2
unnamed: R5.2, SW2.2
unnamed: TP1.1, U2.19 (ADC6)
unnamed: TP2.1, U2.22 (ADC7)
unnamed: TP9.1, U2.23 (PC0)
unnamed: TP10.1, U2.24 (PC1)
unnamed: TP11.1, U2.25 (PC2)
unnamed: TP12.1, U2.26 (PC3)
unnamed: TP13.1, U2.27 (PC4)
unnamed: TP14.1, U2.28 (PC5)
unnamed: TP15.1, U2.2 (PD4)
unnamed: TP16.1, U2.9 (PD5)
unnamed: TP17.1, U2.10 (PD6)
SPI_MISO: IC1.15 (MISO), TP7.1, U2.16 (PB4)
SPI_MOSI: IC1.16 (MOSI), IC2.6 (3Y), JP6.1 (A)
SPI_SCLK: IC1.13 (SCLK), IC2.2 (1Y), JP4.1 (A)
TTL_MAX3421_RESET: IC2.9 (4A), JP3.2 (B), U2.11 (PD7)
TTL_SPI_MOSI: IC2.7 (3A), JP6.2 (B), TP6.1, U2.15 (PB3)
TTL_SPI_SCLK: IC2.3 (1A), JP4.2 (B), TP8.1, U2.17 (PB5)
TTL_SS: IC2.5 (2A), JP5.2 (B), TP5.1, U2.14 (PB2)
VBUS: C1.1, F1.2, J2.1, JP1.3 (B), JP2.3 (B), U1.3 (VI)
VCC: C14.1, C15.1, C16.1, JP2.2 (C), U2.4 (VCC), U2.6 (VCC), U2.18 (AVCC); also elsewhere on the board

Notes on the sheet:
References: https://www.arduino.cc/en/uploads/Main/Arduino-Pro-Mini-schematic.pdf https://www.arduino.cc/en/uploads/Main/arduino-uno-smd-schematic.pdf https://www.sparkfun.com/datasheets/DevTools/Arduino/USBHostShield-v13.pdf
Input Power
CL=(C1*C2)/(C1+C2) + Cstray CL = 9pF Cstray = 5pF C1, C2 = 4pF
CL=(C1*C2)/(C1+C2) + Cstray CL = 20pF Cstray = 5pF C1, C2 = 30pF
Only needed if the ATMEGA is running at 5v
Cut if ATMEGA is running at 5v

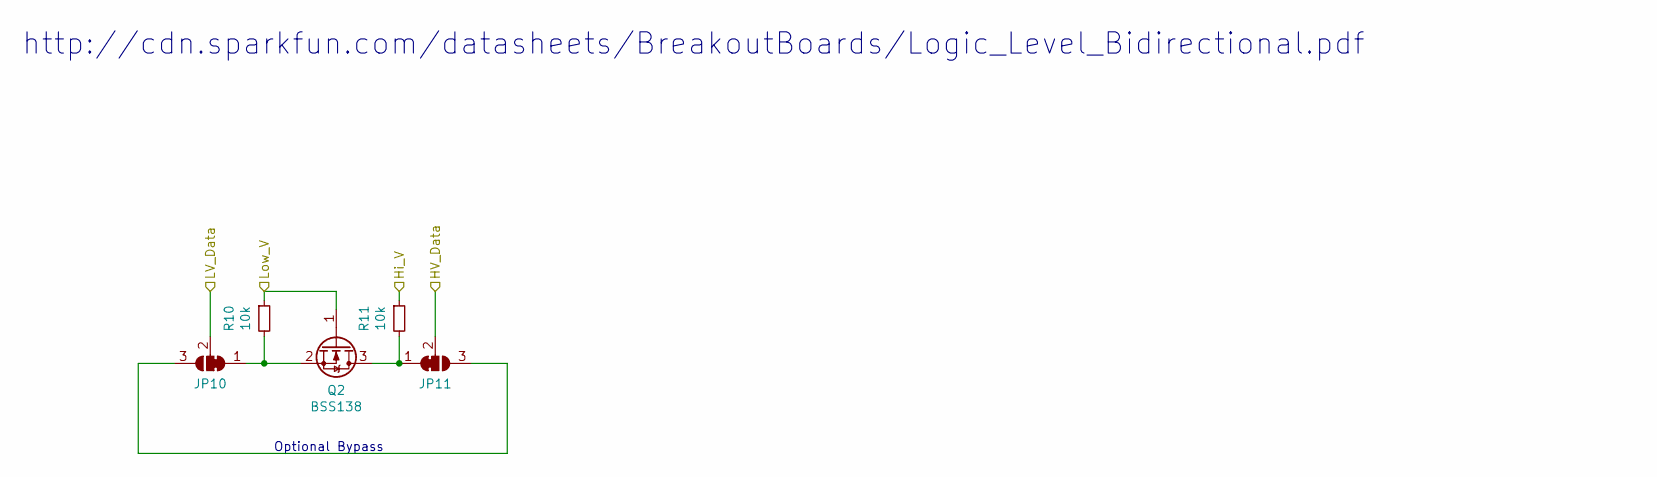
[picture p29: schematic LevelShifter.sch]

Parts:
JP8, JP9: SolderJumper_3_Bridged12; SolderJumper-3_P1.3mm_Bridged12_RoundedPad1.0x1.5mm_NumberL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
Q1: BSS138; SOT-23; LCSC C52895
R8, R9: 10k; R_0805_2012Metric; LCSC C17414

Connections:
ADB_1_5v: R9.1; also elsewhere on the board
ADB_1_DATA: JP9.2 (C); also elsewhere on the board
ADB_DATA_LV: JP8.2 (C); also elsewhere on the board
unnamed: JP8.1 (A), Q1.2 (S), R8.2
unnamed: JP8.3 (B), JP9.3 (B)
unnamed: JP9.1 (A), Q1.3 (D), R9.2
VCC: Q1.1 (G), R8.1; also elsewhere on the board

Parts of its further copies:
JP10, JP11: SolderJumper_3_Bridged12; SolderJumper-3_P1.3mm_Bridged12_RoundedPad1.0x1.5mm_NumberL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
Q2: BSS138; SOT-23; LCSC C52895
R10, R11: 10k; R_0805_2012Metric; LCSC C17414

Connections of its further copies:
ADB_1_5v: R11.1; also elsewhere on the board
ADB_1_PWR_ON: JP11.2 (C); also elsewhere on the board
ADB_PWR_ON_LV: JP10.2 (C); also elsewhere on the board
unnamed: JP10.1 (A), Q2.2 (S), R10.2
unnamed: JP10.3 (B), JP11.3 (B)
unnamed: JP11.1 (A), Q2.3 (D), R11.2
VCC: Q2.1 (G), R10.1; also elsewhere on the board

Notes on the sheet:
http://cdn.sparkfun.com/datasheets/BreakoutBoards/Logic_Level_Bidirectional.pdf
Optional Bypass

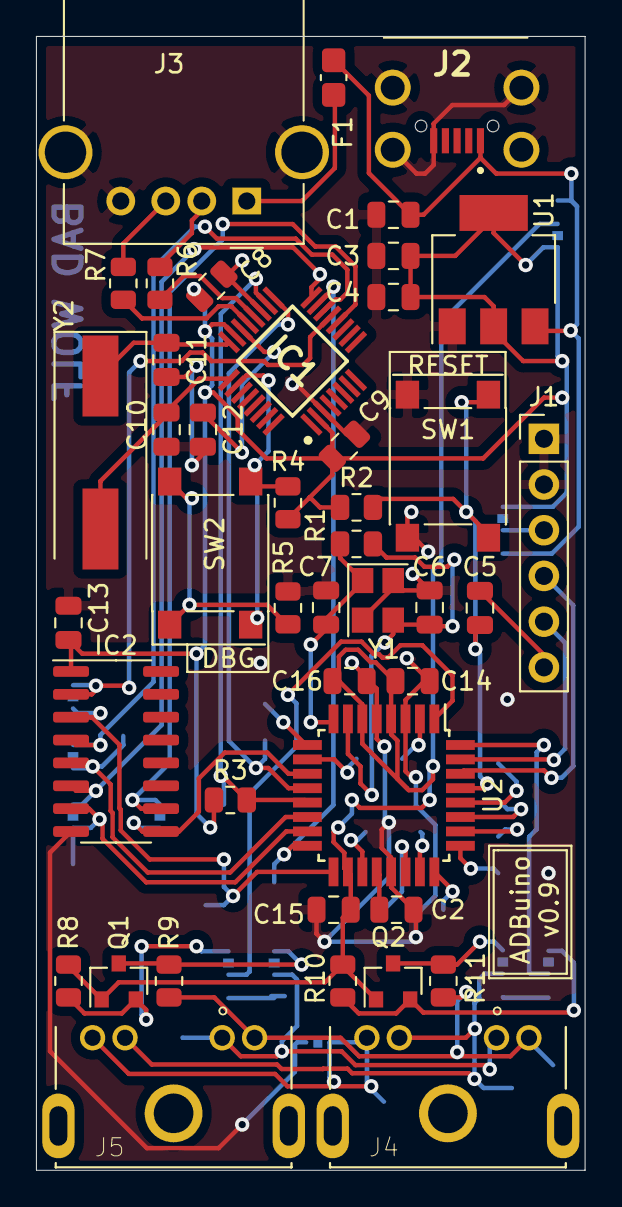
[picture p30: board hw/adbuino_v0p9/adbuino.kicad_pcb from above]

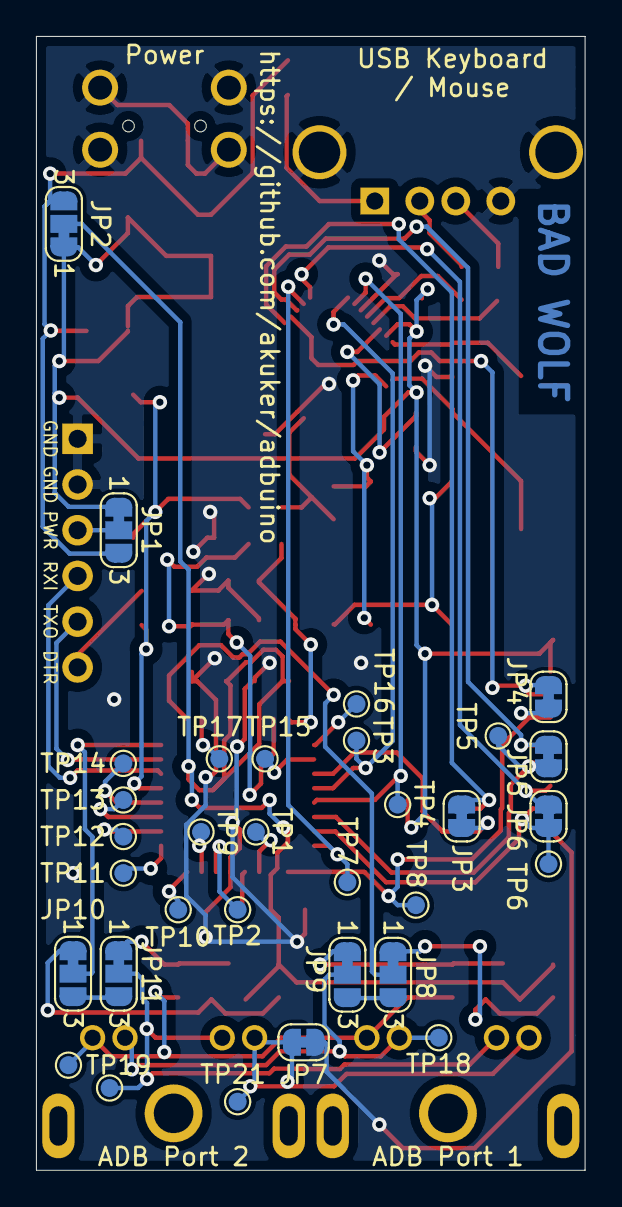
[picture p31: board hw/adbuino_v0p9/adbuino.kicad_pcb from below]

Board: 2 copper layers, 30.5 x 63.0 mm, 75 parts (32 on the bottom side), 56 nets.

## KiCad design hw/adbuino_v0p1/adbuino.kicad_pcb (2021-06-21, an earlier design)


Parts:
A1: Arduino_Nano_v3.x; Arduino_Nano
J1, J2: Mini-DIN-6; TE_5749180-1
J3, J4: Mini-DIN-4; CUI_MD2-40ST
JP1: SolderJumper_2_Bridged; SolderJumper-2_P1.3mm_Bridged_RoundedPad1.0x1.5mm
TP1, TP2, TP3, TP4, TP5, TP6, TP7, TP8, TP9, TP10, TP11, TP12: TestPoint_Small; TestPoint_Pad_D1.0mm

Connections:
ADB_1_5v: A1.12 (D9), J3.3, J4.3, TP11.1
ADB_1_DATA: A1.2 (D0/RX), J3.1, J4.1, TP9.1
ADB_1_GND: J1.3, J2.3, J3.4, J4.4, JP1.2 (B), TP8.1, TP12.1
ADB_1_PWR_ON: A1.1 (D1/TX), J3.2, J4.2, TP10.1
GND: A1.4 (GND), A1.11 (D8), A1.29 (GND), JP1.1 (A)
unnamed: J1.2, TP2.1
unnamed: J1.6, TP1.1
unnamed: J2.2, TP4.1
unnamed: J2.6, TP3.1
PS2_1_5v: A1.9 (D6), J1.4, J2.4, TP7.1
PS2_1_CLK: A1.24 (A5), J1.5, J2.5, TP6.1
PS2_1_Data: A1.23 (A4), J1.1, J2.1, TP5.1



Board: 2 copper layers, 34.0 x 67.3 mm, 18 parts (13 on the bottom side), 12 nets.

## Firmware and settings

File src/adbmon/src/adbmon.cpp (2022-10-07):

//---------------------------------------------------------------------------
//
//	ADBuino ADB keyboard and mouse adapter
//
//     Copyright 2011 Jun WAKO <wakojun@gmail.com>
//     Copyright 2013 Shay Green <gblargg@gmail.com>
//	   Copyright (C) 2017 bbraun
//	   Copyright (C) 2020 difegue
//	   Copyright (C) 2021-2022 akuker
//
//  This file is part of ADBuino.
//
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
//  Portions of this code were originally released under a Modified BSD 
//  License. See LICENSE in the root of this repository for more info.
//
//----------------------------------------------------------------------------
#include "Arduino.h"
#include <util/delay.h>
#define kModCmd 1
#define kModOpt 2
#define kModShift 4
#define kModControl 8
#define kModReset 16
#define kModCaps 32
#define kModDelete 64
uint8_t mousepending = 0;
uint8_t kbdpending = 0;
uint8_t kbdskip = 0;
uint16_t kbdprev0 = 0;
uint16_t mousereg0 = 0;
uint16_t kbdreg0 = 0;
uint8_t kbdsrq = 0;
uint8_t mousesrq = 0;
uint8_t modifierkeys = 0xFF;
uint32_t kbskiptimer = 0;
#define ADB_PORT PORTD
#define ADB_PIN PIND
#define ADB_DDR DDRD
#define ADB_DATA_BIT 3

#define ARRAY_SIZE(x) (sizeof(x) / sizeof(x[0]))

enum e_command_code_t : uint8_t
{
  // The SendReset command causes all devices on the network to reset to their
  // power-on states
  SendReset,
  // The action of the Flush command is defined for each device. Normally, it
  // is used to clear any internal registers in the device
  Flush,
  // The Listen command is a request for the device to receive data transmitted
  // from the computer and store it in a specific internal register (0 through 3).
  Listen,
  // The Talk command initiates a data transfer to the computer from a specific
  // register (0 through 3) of an ADB input devic
  Talk,
  // Not used
  Reserved,
};

// The original data_lo code would just set the bit as an output
// That works for a host, since the host is doing the pullup on the ADB line,
// but for a device, it won't reliably pull the line low.  We need to actually
// set it.
#define data_lo()                       \
  {                                     \
    (ADB_DDR |= (1 << ADB_DATA_BIT));   \
    (ADB_PORT &= ~(1 << ADB_DATA_BIT)); \
  }
#define data_hi() (ADB_DDR &= ~(1 << ADB_DATA_BIT))
#define data_in() (ADB_PIN & (1 << ADB_DATA_BIT))
static inline uint16_t wait_data_lo(uint16_t us)
{
  do
  {
    if (!data_in())
      break;
    _delay_us(1 - (6 * 1000000.0 / F_CPU));
  } while (--us);
  return us;
}
static inline uint16_t wait_data_hi(uint16_t us)
{
  do
  {
    if (data_in())
      break;
    _delay_us(1 - (6 * 1000000.0 / F_CPU));
  } while (--us);
  return us;
}

static inline void place_bit0(void)
{
  data_lo();
  _delay_us(65);
  data_hi();
  _delay_us(35);
}
static inline void place_bit1(void)
{
  data_lo();
  _delay_us(35);
  data_hi();
  _delay_us(65);
}
static inline void send_byte(uint8_t data)
{
  for (int i = 0; i < 8; i++)
  {
    if (data & (0x80 >> i))
      place_bit1();
    else
      place_bit0();
  }
}
static uint8_t inline adb_recv_cmd(uint8_t srq)
{
  uint8_t bits;
  uint16_t data = 0;

  // find attention & start bit
  if (!wait_data_lo(5000))
    return 0;
  uint16_t lowtime = wait_data_hi(1000);
  if (!lowtime || lowtime > 500)
  {
    return 0;
  }
  wait_data_lo(100);

  for (bits = 0; bits < 8; bits++)
  {
    uint8_t lo = wait_data_hi(130);
    if (!lo)
    {
      goto out;
    }
    uint8_t hi = wait_data_lo(lo);
    if (!hi)
    {
      goto out;
    }
    hi = lo - hi;
    lo = 130 - lo;

    data <<= 1;
    if (lo < hi)
    {
      data |= 1;
    }
  }

  if (srq)
  {
    data_lo();
    _delay_us(250);
    data_hi();
  }
  else
  {
    // Stop bit normal low time is 70uS + can have an SRQ time of 300uS
    wait_data_hi(400);
  }

  return data;
out:
  return 0;
}

void Handle_Listen()
{
  // When the computer sends a Listen command to a device, the device
  // receives the next data packet from the computer and places it in
  // the appropriate register. After the stop bit following the data is
  // received, the transaction is complete and the computer releases the bus
}
int Receive_ADB_Data(uint8_t *data_buf, int buf_size)
{
  // When the computer sends a Talk command to a device, the device must
  // respond with data within 260 µs. The selected device performs its
  // data transaction and releases the bus, leaving it high
  uint8_t bits;
  uint16_t data = 0;
  int word_count = 0;

  uint8_t x = wait_data_lo(260);
  if(!x){
    return word_count;
  }

  for (int i = 0; i < 8; i++)
  {
    if (word_count > buf_size)
    {
      Serial.println("Warning! Buffer overflow in Receive_ADB_Data. Data may be lost");
      return word_count;
    }

    for (bits = 0; bits < 8; bits++)
    {
      uint8_t lo = wait_data_hi(130);
      if (!lo)
      {
        return word_count;
      }
      uint8_t hi = wait_data_lo(lo);
      if (!hi)
      {
        return word_count;
      }
      hi = lo - hi;
      lo = 130 - lo;

      data <<= 1;
      if (lo < hi)
      {
        data |= 1;
      }
      data_buf[word_count] = data;
    }
    word_count++;
  }
  return word_count;
}

void setup()
{
  Serial.begin(115200);
  while (!Serial)

    // Set ADB line as input
    ADB_DDR &= ~(1 << ADB_DATA_BIT);

  Serial.println("setup complete");
}

void loop()
{
  uint8_t cmd = 0;
  e_command_code_t cmd_code = Reserved;
  uint8_t cmd_register = 0;
  uint8_t cmd_address = 0;
  int blk_size = 0;
  uint8_t data_buffer[8]; // Max size of a ADB transaction is 8 bytes
  memset(data_buffer, 0, sizeof(data_buffer));
  char cmd_str[64];
  // uint16_t us;

  cmd = adb_recv_cmd(mousesrq | kbdsrq);
  if (cmd != 0)
  {
    cmd_register = (cmd & 0x03);
    cmd_address = ((cmd & 0xF0) >> 4);

    switch ((cmd & 0x0C) >> 2)
    {
    case 0x0:
      switch (cmd & 0x01)
      {
      case 0x0:
        cmd_code = SendReset;
        strcpy(cmd_str, "Reset");
        break;
      case 0x1:
        cmd_code = Flush;
        strcpy(cmd_str, "Flush");
      }
      break;
    case 0x2:
      cmd_code = Listen;
      strcpy(cmd_str, "Listen");
      break;
    case 0x3:
      cmd_code=Talk;
      strcpy(cmd_str, "Talk");
      break;
    default:
      strcpy(cmd_str, "Invalid");
    }

    switch (cmd_code)
    {
    case Talk:
    case Listen:
      blk_size = Receive_ADB_Data(data_buffer, ARRAY_SIZE(data_buffer));

      if (blk_size > 0)
      {
        Serial.print("ADB Command:");
        Serial.print(cmd, HEX);
        Serial.print(" (");
        Serial.print(cmd_str);
        Serial.print(") addr:");
        Serial.print(cmd_address, HEX);
        Serial.print(" reg:");
        Serial.print(cmd_register);
        Serial.print(" Data[");
        Serial.print(blk_size);
        Serial.print("]: ");
        for (int i = 0; i < blk_size; i++)
        {
          Serial.print(data_buffer[i], HEX);
        }
              Serial.println("");

      }
      break;
    case SendReset:
    case Flush:
    default:
      break;
    }
    
  }
}

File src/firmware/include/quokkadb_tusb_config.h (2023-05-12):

/**
 * QuokkADB
 * Copyright (C) 2022 Rabbit Hole Computing LLC
 * This file is derived from hathach's (tinyusb.org) TinyUSB
 * 
 * 4 October 2022 - Modified by Rabbit Hole Computing LLC
 */

/*
 * The MIT License (MIT)
 *
 * Copyright (c) 2019 Ha Thach (tinyusb.org)
 *
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
 */

#ifndef _QUOKKADB_TUSB_CONFIG_H_
#define _QUOKKADB_TUSB_CONFIG_H_

#ifdef __cplusplus
 extern "C" {
#endif
// #include "hardware/uart.h"
//--------------------------------------------------------------------
// COMMON CONFIGURATION
//--------------------------------------------------------------------

#define CFG_TUSB_OS               OPT_OS_PICO
#define CFG_TUSB_MCU              OPT_MCU_RP2040 

// Enable host stack 
#define CFG_TUH_ENABLED     1

// CFG_TUSB_DEBUG is defined by compiler in DEBUG build
#define CFG_TUSB_DEBUG 0
//#define CFG_TUSB_DEBUG 3


/* USB DMA on some MCUs can only access a specific SRAM region with restriction on alignment.
 * Tinyusb use follows macros to declare transferring memory so that they can be put
 * into those specific section.
 * e.g
 * - CFG_TUSB_MEM SECTION : __attribute__ (( section(".usb_ram") ))
 * - CFG_TUSB_MEM_ALIGN   : __attribute__ ((aligned(4)))
 */
#ifndef CFG_TUSB_MEM_SECTION
#define CFG_TUSB_MEM_SECTION
#endif

#ifndef CFG_TUSB_MEM_ALIGN
#define CFG_TUSB_MEM_ALIGN          __attribute__ ((aligned(4)))
#endif

//--------------------------------------------------------------------
// HOST CONFIGURATION
//--------------------------------------------------------------------

// Size of buffer to hold descriptors and other data used for enumeration
#define CFG_TUH_ENUMERATION_BUFSIZE 1024

#define CFG_TUH_HUB                 7
// max device support (excluding hub device)
#define CFG_TUH_DEVICE_MAX          14 // hub typically has 4 ports
#define CFG_TUH_HID                 4 // typical keyboard + mouse device can have 3-4 HID interfaces
#define CFG_TUH_MSC                 0

#define CFG_TUH_HID_EPIN_BUFSIZE    64
#define CFG_TUH_HID_EPOUT_BUFSIZE   64




#ifdef __cplusplus
 }
#endif

#endif /* _QUOKKADB_TUSB_CONFIG_H_ */

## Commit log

2021-06-21 Redraw schematic in Kicad
    [adbuino.kicad_pcb, adbuino.sch]
2021-07-05 pulled in readme changes from pico branch
2021-07-06 Added first cut of keyboard functionality.
2021-07-06 Include mouse button in check if the mouse register has changed
2021-07-07 Simple tool for printing out adb activity. Currently only has listen and talk commands implemented
2021-07-07 First draft of 0.9
    [MAX3421EEHJ+.stl, MAX3421EEHJ+.stp, adbuino.kicad_pcb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]
2021-07-07 Finished initial board layout
    [LevelShifter.sch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]
2021-07-07 Regenerated schematic
2021-07-25 Fixes from version 0.9
    [LevelShifter.sch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]
2021-07-28 First round of routing completed
    [LevelShifter.sch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]
2021-08-08 pogo holder
    [adbuino_case.FCStd, adbuino_case.stl]
2021-08-09 Updated hole size to 1.2mm
    [adbuino_case.FCStd, adbuino_case.stl, adbuino_pogo_holder.FCStd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]
2021-08-10 Added 3d models for connectors
    [MD2-40ST-SMT.FCStd]
2021-08-15 Remove reset of Max3421E and Added optional USB listing
    [adb.cpp, adbmon.cpp]
2021-08-16 remove old gerbers
    [adbuino-B_Cu.gbr, adbuino-B_Mask.gbr, adbuino-B_Paste.gbr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]
2021-08-22 Created version 1.0 of USB ADBuino
    [LevelShifter.sch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]
2021-09-25 illustrate how adb connector connects to arduino
2022-03-21 Case first draft
    [adbuino_case2.FCStd]
2022-03-22 Updated to be slim
    [adbuino_case2.FCStd]
2022-10-06 Add a Serial.print functionality to QuokkADB
    A minimal implementation of Arduino's Serial.print and Serial.println.
    Currently printing text via the SWO UART TX pin. This should allow
    more files being shared between the two projects.
2022-10-10 Add files to the shared library
    This code hasn't been tested, but it does compile.
    There are probably some race conditions in QuokkADB code
    with the globals.
    This is probably a good place to stop while without being able
    to test the code on the devices.
2022-10-11 QuokkADB in a minimal working state
    Keyboard and mouse work, but cap lock and keyboard LEDs do not.
2022-10-19 Numerous fixes
    Mouse - set handler id to 1 (default mouse handler id)
    Keyboard - set right modifier keys to map to left modifier keys
    Printf library - set to v6.0.0 (broke on latest build)
    LED - shortened blink time
    Set timeout looking for ADB host command to an arbitrary long number
2022-10-27 Basic collision works
    Tested with two QuokkADB boards, both on LISTEN reg3 and reg0
    with two mice the new firmware detected collisions. When
    by itself no collisions are detected.
2022-11-02 Collision detection and reassigning address works
    Code is in more of a working state. Reassigning of device
    address works. Not sure how well they work. Outputting over serial
    can cause issues in missing commands so most of the debug messages
    are really for code comments.
2022-11-15 Use F15 or Pause key as Apple Power key
2022-12-20 The extended keyboard features work with a bug
    The extended keyboard works, but there is an issue with the
    LED lock lights stop changing after a bit.
    [quokkadb_tusb_config.h]
2022-12-28 Trying to fix the Keyboard lock LEDs
    [quokkadb_tusb_config.h]
2022-12-29 Virtually type the firmware version
    The code now recognizes CTRL+SHIFT+CAPSLOCK+V to print out the
    firmware version.
2022-12-29 Move fake power button to prtsc/sysrq/F13
    This is to better mirror the USB wombat
2022-12-30 Multi-mode right click
    The middle button toggles between ctrl + left_click and
    right_click modes for the right mouse button.
2023-01-11 Enable/disable busy LED and save for power cycle
    Add the ability to turn on or off the busy LED blinking. Save
    the setting to flash and use it when the board is powered on again.
2023-02-24 Build QuokkADB with cmake for new pico sdk
    Wizio on platformio doesn't support the latest pico SDK.
    Building with cmake allows the project to use the new
    SDK version.
    [quokkadb.h]
2023-03-19 as-ordered adbuino
    [LevelShifter.kicad_sch, MD2-40ST-SMT.FCStd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]
2023-03-27 Fix and remove DEBUG committed
    Fixed and removed code with the DEBUG label.
    Removed code that was commented out.
    Added some hints on how to debug using vscode and a picoprobe.
    Added compile date and time to firmware string.
    Removed QuokkADB compile option from platformio.ini as compiling
    has been moved the CMake.
    [quokkadb.h, quokkadb_tusb_config.h]
2023-03-28 Clarify how to shunt BOOTLDR pin header
2023-05-09 Modifier keys and special key combo
    Added back modifier keys working when held down. Also
    added the ability to print out the firmware version.
2023-05-09 Caps lock behaves correctly
    Fixed caps lock functionality. Also forced caps lock off
    when printing out the version string.
2023-05-10 Turn off USB verbose error logging
    When it is on, the QuokkADB misses two consecutive ADB events,
    causing the mouse and keyboard to be delayed and jerky.
    [quokkadb_tusb_config.h]
2023-05-11 Fix unreliable booting
    The cause seems to be bad signaling when the QSPI flash is running
    at 75MHz. Halving the flash clock speed makes booting solid.
    Also the delays have been removed from the boot process as they were
    a legacy from a different code base and not needed in this design.
    The LED blinking inserts delays anyways.
    Changed the initial blinking on boot. First it immediately blinks
    once first first core is up, then it blinks once again the second
    core is up and after tiny usb host has been initialized.
    [quokkadb.h]
2023-08-22 add the jlcpcb production files
    [BOM-adbuino.csv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]
2023-11-16 Switch QuokkADB back to PlatformIO
    Moved QuokkADB back to the PlatformIO building process from CMake.
    This time using a custom spin of the earlephilhower arduinopico
    framework that includes USB host support.
    The biggest code change to support this is using a wrapper around
    Arduino Serial library for ADBuino and for QuokkADB using
    the same wrapper interface but using pico/printf as the underlying
    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
2023-11-29 Change the mouse event processing
    The mouse now ignores any queued events besides the most recent
    or if the is a button status change.
    There is still work that needs to be done before release.
    - It needs to built against ABDuino
    - Resetting the mouse events has not been implemented
2023-11-30 Change LED blinking to non blocking
    The LED blinking for initialization and USB enumeration now
    no longer blocks and the USB devices should enumerate sooner.
    Also placed as much of the code as possible into SRAM using
    a linker script adopted from ZuluSCSI.
2023-12-01 Update TinyUSB to 0.16.0, change LED blink timing
    Updating TinyUSB seems to stop the behavior where the devices sometimes
    do no enumerate.
    Changed LED blink timing so it is more readable.
2023-12-08 Only respond to talk reg 3 after flush
    The previous code would cause the ADB driver to think
    there was a mouse and keyboard on all addresses.
    This was due to the mouse and keyboard responding to talk reg 3
    before a flush was sent to the device.
    Now the devices will only respond to a to talk reg 3 after a reset
    and a flush has occurred. Which the ADB driver now only displays
    the one two devices.
2023-12-13 Use an accumulator to keep track of fine movement
    This approach uses a accumulator to keep track of fine mouse movement.
    The accumulator then increments the ADB mouse movement by
    the accumulator / the sensitivity divisor. This does create a little
    bit of a dead zone, but as long as the mouse continue to move
    in one direction the cursor will still move no matter how long
    the wait between movements.
    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
2023-12-14 Move accumulators to USB mouse parser
    Instead of queuing all the mouse movements incoming from USB,
    moved the summing of mouse movements to the USB parser. Still
    have to queue button changes, but they occur less frequently
    and allow for a shorter queue with less data per entry.
2023-12-19 Some good ideas, not working with Gravis gamepad
    There are some positive fixes in the commit, but breaks when a Gravis
    gamepad is on the ADB bus.
    It sometimes enumerates the devices the same as the Wombat,
    but then it queries all the addresses between mouse moves.
    In another case it seems to work but the enumeration is off.
    The keyboard gets moved to address 0xF and the Gravis gamepad
    is at address 0x2 (keyboard's default address).
2024-01-02 Getting ready to spin a new release
    Bumped to version 0.5.0-beta. Removed `GPIO_TRIGGER_LOWER()` and
    `GPIO_TRIGGER_RAISE()` debug triggers. Updated README.md and
    QuokkADB.md. Removed unused variables. Switched code to running
    from SRAM instead of Flash.
2024-01-06 Fix right mouse button and QuokkADB freezing
    The right mouse button wasn't lifting Control after being lifted.
    The fix for this also seems to fix the QuokkADB freezing after a while.
    The freezing only occurred in the release build. Under the
    debug build it worked fine.
    A possible memory leak was also addressed in the simple circular queue.
    Pointers to objects get the `delete` if the queue is full.

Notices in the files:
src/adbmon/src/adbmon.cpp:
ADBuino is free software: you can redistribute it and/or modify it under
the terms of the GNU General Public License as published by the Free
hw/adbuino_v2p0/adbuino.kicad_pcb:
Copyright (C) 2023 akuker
